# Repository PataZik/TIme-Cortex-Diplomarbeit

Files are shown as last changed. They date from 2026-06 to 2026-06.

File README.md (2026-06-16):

"# TIme-Cortex-Diplomarbeit" 

| Schüler/in | Individuelle Themenstellung | Abteilung | Verantwortlich |
|---|---|---|---|
| Patrik Alzo | Implementierung einer Datenbank zur Speicherung der Arbeitszeitdaten sowie Entwicklung eines passenden Gehäuses. | IF | |
| Wessel Reinier de Koo |  Entwurf und Umsetzung einer Platine für ein RFID-Zeiterfassungssystem mit geeigneten Mikrocontrollern und Komponenten. | IF | Ja |
| Dorde Dimitrijevic | Umsetzung einer Webanwendung zur Darstellung und Verwaltung der im RFID-System erfassten Arbeitszeiten. | IF | |
| Pascal Zierl | Entwicklung eines stabilen Programmcodes für die sichere Verarbeitung und Übertragung von RFID-Daten im Zeiterfassungssystem. | IF | |

De Koo Wessel Reinier
Auswahl und Testung verschiedener Mikrocontroller und weiterer Bauteile. Planung und Erstellung einer eigenen Platine sowie Zusammenbau aller Komponenten. Sicherstellung der Funktionsfähigkeit und Effizienz des Gesamtsystems.

Zierl Pascal
Entwicklung eines funktionierenden und kompatiblen Codes, der die erfassten Daten zuverlässig an die Webanwendung übermittelt und dabei die Sicherheit der Daten gewährleistet.

Dimitrijevic Dorde
Erstellung einer Webanwendung zum Zugriff auf die erfassten Daten. Eine zentrale Funktion ist die Einsicht der dokumentierten Arbeitszeiten über eine benutzerfreundliche Oberfläche.

Alzo Patrik
Planung, Test und Erstellung einer Datenbank zur Speicherung der erfassten Daten. Zusätzlich Konstruktion, Druck und Prüfung eines selbst entworfenen Gehäuses für die Hardware.

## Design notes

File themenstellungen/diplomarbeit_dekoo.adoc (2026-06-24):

== Themenstellung von Wessel de Koo

[.lead]
Eine funktionsfähige, getestete Platine mit RFID-Lesegerät, die Mitarbeiterchips fehlerfrei erkennt und die Daten an die nachfolgenden Systeme weitergibt.
Das Modul bildet die Grundlage für die gesamte Zeiterfassung.

Die vorliegende Arbeit ist Teil des Gesamtprojekts _TimeCortex_, eines RFID-gestützten Zeiterfassungssystems.
Während sich andere Teilarbeiten mit dem Gehäuse, der Datenbank und der Weboberfläche befassen, behandelt dieser Abschnitt die zentrale Hardwarekomponente: eine eigens entworfene Leiterplatte, auf der ein Mikrocontroller, ein RFID-Lesemodul, ein Display sowie eine akkugepufferte Stromversorgung zusammengeführt werden.
Das Untersuchungsanliegen umfasst die Auswahl und Testung verschiedener Mikrocontroller und weiterer Bauteile, die Planung und Erstellung einer eigenen Platine, den Zusammenbau aller Komponenten sowie die Sicherstellung der Funktionsfähigkeit und Effizienz des Gesamtsystems.

Die Arbeit folgt dabei bewusst dem realen Entwicklungsverlauf:
Zunächst werden die theoretischen Grundlagen der eingesetzten Technologien erläutert, anschließend wird die Bauteilauswahl begründet, danach das Platinendesign beschrieben und schließlich die Fertigung, Bestückung und schrittweise Inbetriebnahme des Prototyps dokumentiert.

=== Theoretische Grundlagen

Bevor konkrete Bauteile ausgewählt und zu einer Schaltung verbunden werden können, ist ein Verständnis der zugrunde liegenden Technologien erforderlich.
Dieses Kapitel beschreibt daher zunächst allgemein das Funktionsprinzip der RFID-Technologie, die Einordnung von Mikrocontrollern gegenüber Mikrocomputern und die grundlegenden Begriffe des Leiterplattenentwurfs.
Erst auf dieser Basis lassen sich die späteren Entwurfsentscheidungen nachvollziehbar begründen.

==== RFID-Technologie

_RFID_ steht für _Radio-Frequency Identification_ und bezeichnet ein Verfahren zur kontaktlosen Identifikation von Objekten über elektromagnetische Felder (vgl. <<wiki-rfid>>).
Ein RFID-System besteht grundsätzlich aus zwei Komponenten: einem _Lesegerät_ (Reader, in der Normsprache _PCD_ – Proximity Coupling Device) und einem _Transponder_ (Tag, in der Normsprache _PICC_ – Proximity Integrated Circuit Card).
Der Transponder trägt einen kleinen Mikrochip mit einer eindeutigen Kennung sowie eine Antenne in Form einer Spule.

Man unterscheidet grundsätzlich zwischen _aktiven_ und _passiven_ Transpondern.
Aktive Transponder besitzen eine eigene Energiequelle und können dadurch größere Reichweiten erzielen, sind aber teurer und wartungsbedürftig.
Passive Transponder – wie die in dieser Arbeit verwendeten Mitarbeiterchips – besitzen keine eigene Energieversorgung, sondern beziehen die zum Betrieb nötige Energie aus dem Feld des Lesegeräts.
Genau diese Eigenschaft macht sie für eine Zeiterfassung ideal:
Die Chips sind günstig, wartungsfrei und praktisch unbegrenzt haltbar.

Das physikalische Grundprinzip eines passiven HF-Systems ist die _induktive Kopplung_.
Das Lesegerät erzeugt über seine Antennenspule ein magnetisches Wechselfeld mit einer Trägerfrequenz von 13,56 MHz.
Befindet sich die Spule des Transponders in diesem Feld, so wird darin nach dem Induktionsgesetz eine Spannung induziert, die den Chip mit Energie versorgt – das System verhält sich also wie ein lose gekoppelter Transformator (vgl. <<iso-14443-guide>>).
Die Datenübertragung vom Transponder zurück zum Lesegerät erfolgt durch _Lastmodulation_:
Der Transponder verändert im Takt seiner Antwortdaten den Stromverbrauch seiner Spule, was als kleine Rückwirkung im Feld des Lesegeräts messbar ist.

Damit eine effiziente Energie- und Signalübertragung stattfindet, müssen Lese- und Transponderantenne auf die Trägerfrequenz abgestimmt sein.
Die Resonanzfrequenz eines solchen Schwingkreises aus Spuleninduktivität latexmath:[L] und Kapazität latexmath:[C] ergibt sich aus der bekannten Thomson-Gleichung:

[latexmath]
++++
f_{res} = \frac{1}{2\pi\sqrt{L\,C}}
++++

Für 13,56 MHz wird die Antenne also so dimensioniert, dass latexmath:[f_{res}] möglichst nahe an der Trägerfrequenz liegt.
Eine schlecht abgestimmte Antenne verringert die Reichweite drastisch – ein Aspekt, der beim späteren Platinenlayout zu beachten ist, da Kupferflächen und Bauteile in der Nähe der Antenne deren Abstimmung verstimmen können.

Auf der Protokollebene ist für diese Arbeit die Normenfamilie _ISO/IEC 14443_ maßgeblich, die den De-facto-Standard für kontaktlose Chipkarten im Nahbereich (bis etwa 10 cm) definiert (vgl. <<iso-14443-guide>>).
Die Norm gliedert sich in mehrere Teile, die jeweils einen Aspekt der Kommunikation festlegen.

.Aufbau der Normenfamilie ISO/IEC 14443
[cols="1,3",options="header"]
|===
| Teil | Inhalt
| Teil 1 | Physikalische Eigenschaften der Karte (Abmessungen, Umweltanforderungen).
| Teil 2 | Hochfrequenz-Leistungs- und Signalschnittstelle (Modulation, Feldstärke, Typ A und Typ B).
| Teil 3 | Initialisierung und Antikollision – die Auswahl genau einer Karte aus mehreren im Feld.
| Teil 4 | Übertragungsprotokoll für den Datenaustausch nach erfolgter Auswahl.
|===

Innerhalb dieser Norm ist die von NXP entwickelte _MIFARE_-Familie der mit Abstand verbreitetste Kartentyp und nutzt die Variante Typ A (vgl. <<mifare-an>>).
Für die Zeiterfassung ist dabei nicht der oft verschlüsselte Speicherinhalt einer MIFARE-Karte entscheidend, sondern bereits die im Antikollisionsverfahren übertragene eindeutige Seriennummer, die _UID_ (Unique Identifier).
Jeder Mitarbeiterchip besitzt eine solche, weltweit praktisch eindeutige UID, die sich ohne Authentifizierung auslesen lässt und damit als digitaler Schlüssel zur Identifikation der Person dient.
Genau diese UID liest das in dieser Arbeit aufgebaute Modul aus und reicht sie an die nachgelagerten Systeme weiter.

Der grundsätzliche Ablauf einer Erfassung lässt sich als Sequenz zwischen Lesegerät und Transponder darstellen.

[plantuml,format=svg]
----
@startuml
skinparam shadowing false
actor "Mitarbeiter" as user
participant "Lesegerät\n(PCD / PN532)" as reader
participant "Chip\n(PICC / MIFARE)" as card

user -> card : Chip an Leser halten
reader -> card : 13,56-MHz-Feld (Energie)
note right of card : Induzierte Spannung\nversorgt den Chip
reader -> card : REQA (Karte im Feld?)
card --> reader : ATQA (Antwort)
reader -> card : Antikollision / SELECT
card --> reader : UID
reader -> reader : UID an Mikrocontroller
@enduml
----

==== Mikrocontroller und Mikrocomputer

Das Herzstück jeder eingebetteten Schaltung ist die Recheneinheit, die Sensoren ausliest, Aktoren ansteuert und die Programmlogik ausführt.
Hier ist begrifflich zwischen einem _Mikrocomputer_ und einem _Mikrocontroller_ zu unterscheiden, da diese Wahl die gesamte Architektur der Platine prägt.

Ein _Mikrocomputer_ – ein typischer Vertreter ist der Raspberry Pi – ist im Kern ein vollwertiger, wenn auch kleiner Computer.
Er besitzt einen leistungsfähigen Prozessor, mehrere hundert Megabyte bis Gigabyte Arbeitsspeicher und führt in der Regel ein vollwertiges Betriebssystem wie Linux aus.
Dadurch eignet er sich für rechenintensive Aufgaben wie Bildverarbeitung oder das Betreiben von Servern, benötigt aber vergleichsweise viel Energie, eine geregelte Stromversorgung und einen Massenspeicher.

Ein _Mikrocontroller_ hingegen ist ein hochintegrierter Ein-Chip-Rechner, der Prozessorkern, Arbeitsspeicher (RAM), Programmspeicher (Flash) und zahlreiche Peripherieschnittstellen auf einem einzigen Baustein vereint.
Er besitzt kein Betriebssystem im klassischen Sinn, sondern führt ein einzelnes, fest eingebranntes Programm (die _Firmware_) aus.
Mikrocontroller sind dafür ausgelegt, mit minimalem Energieverbrauch direkt mit der physischen Welt zu interagieren – sie lesen digitale und analoge Eingänge, schalten Ausgänge und kommunizieren über serielle Busse mit Sensoren und Modulen.

Für ein Zeiterfassungsterminal, das im Wesentlichen einen RFID-Chip auslesen, eine Information anzeigen und das Ergebnis über das Netzwerk versenden soll, ist ein Mikrocontroller die naheliegende Wahl.
Die Aufgabe ist nicht rechenintensiv, dafür sind geringer Stromverbrauch (für den Akkubetrieb), geringe Kosten und eine direkte Anbindung von Peripherie über Busse wie _I²C_ entscheidend.
Ein vollwertiger Mikrocomputer wäre an dieser Stelle deutlich überdimensioniert, teurer und energiehungriger.

Die Kommunikation mit den Peripheriemodulen erfolgt im vorliegenden Projekt überwiegend über den _I²C-Bus_ (Inter-Integrated Circuit).
Dieser serielle Zweidraht-Bus benötigt lediglich zwei Leitungen – eine Taktleitung (_SCL_) und eine Datenleitung (_SDA_) – und erlaubt es, mehrere Bausteine mit jeweils eigener Adresse an denselben zwei Leitungen zu betreiben.
Diese Eigenschaft ist für ein platzsparendes Platinendesign besonders attraktiv, da sowohl das RFID-Modul als auch das Display über dieselben beiden Leitungen angebunden werden können.
Beide Leitungen sind als _Open-Drain_ ausgeführt und benötigen daher Pull-up-Widerstände, ein Detail, das im Schaltungsentwurf wieder aufgegriffen wird.

==== Grundlagen des Platinenentwurfs

Eine _Leiterplatte_ (engl. _Printed Circuit Board_, PCB) ist der mechanische und elektrische Träger einer elektronischen Schaltung.
Sie besteht aus einem isolierenden Grundmaterial – üblicherweise dem glasfaserverstärkten Epoxidharz _FR4_ – auf das eine oder mehrere Lagen Kupfer aufgebracht sind.
Aus diesen Kupferlagen werden durch ein fotochemisches Ätzverfahren die _Leiterbahnen_ herausgearbeitet, welche die Bauteile elektrisch miteinander verbinden und damit die früher übliche fliegende Verdrahtung ersetzen.

Der Entwurf einer Leiterplatte verläuft in zwei klar getrennten Schritten, die auch in dieser Arbeit die Gliederung vorgeben.

Im ersten Schritt entsteht der _Schaltplan_ (Schematic).
Er ist eine rein logische, abstrakte Darstellung der Schaltung:
Er beschreibt, _welche_ Bauteile es gibt und _wie_ sie elektrisch verbunden sind, ohne eine Aussage über ihre physische Anordnung zu treffen.
Bauteile werden durch genormte Symbole repräsentiert, Verbindungen durch Linien (_Netze_).

Im zweiten Schritt folgt das _Layout_ (PCB-Design).
Hier werden die im Schaltplan definierten Bauteile durch ihre realen _Footprints_ – die exakten Lötflächen und Bohrungen des physischen Gehäuses – ersetzt und physisch auf der Platinenfläche platziert.
Anschließend werden die logischen Netze des Schaltplans als reale Kupferbahnen verlegt (das sogenannte _Routing_).
Dabei sind zahlreiche physikalische Randbedingungen zu beachten, etwa Mindestabstände zwischen Leiterbahnen, ausreichende Bahnbreiten für höhere Ströme und eine durchgehende Massefläche zur Verbesserung der Störfestigkeit.

Man unterscheidet Leiterplatten nach der Anzahl ihrer Kupferlagen.
Einfache Schaltungen kommen mit einer einseitigen Platine aus, während komplexe Designs vier oder mehr Lagen benötigen.
Für das vorliegende Projekt wurde eine _zweilagige_ Platine gewählt, die einen guten Kompromiss zwischen Fertigungskosten und Verdrahtungsfreiheit darstellt:
Die Bauteile und der Großteil der Signale liegen auf der Oberseite, während die Unterseite überwiegend als durchgehende Massefläche und für kreuzende Verbindungen genutzt wird.
Verbindungen zwischen den beiden Lagen werden über metallisierte Bohrungen, sogenannte _Vias_, hergestellt.

Der gesamte Entwurf wurde in der webbasierten EDA-Software _EasyEDA_ erstellt, deren Projektdateien (Schaltplan und Layout) eine zentrale Quelle dieser Arbeit bilden.
EasyEDA ist eng mit dem Fertiger JLCPCB sowie dem Bauteilkatalog von LCSC verzahnt, wodurch ein durchgängiger Weg vom Schaltplan bis zur bestellten Platine entsteht.

=== Recherche der optimalen Komponenten

Ein wesentlicher Teil dieser Arbeit bestand in der sorgfältigen Auswahl der Bauteile.
Diese Recherche nahm – wie aus dem Begleitprotokoll ersichtlich – einen erheblichen Anteil der Projektzeit in Anspruch, da jede Komponente nicht nur ihre Funktion erfüllen, sondern auch hinsichtlich Betriebsspannung, Schnittstellen, Verfügbarkeit, Lieferzeit und Kosten zum Gesamtsystem passen muss.
Dieses Kapitel begründet die getroffene Auswahl, indem es jeweils zunächst die Anforderungen und alternative Lösungen darstellt und anschließend die konkrete Entscheidung herleitet.

==== Vergleich und Auswahl des Mikrocontrollers

Als zentrale Anforderung an den Mikrocontroller galt eine integrierte WLAN-Schnittstelle, da die erfassten Zeitstempel an ein nachgelagertes Backend übertragen werden müssen.
Weiterhin waren ein niedriger Energieverbrauch für den Akkubetrieb, eine ausreichende Anzahl an GPIO-Pins, ein I²C-Controller sowie geringe Kosten und gute Verfügbarkeit gefordert.

Für die Vorauswahl wurden drei in der Praxis verbreitete Plattformen gegenübergestellt.

.Vergleich möglicher Mikrocontroller-Plattformen
[cols="1,1,1,1",options="header"]
|===
| Kriterium | ATmega328P (Arduino Uno) | ESP8266 | ESP32-C3
| Funk | keiner | WLAN | WLAN + Bluetooth LE
| Kern | 8-bit AVR, 16 MHz | 32-bit, 80 MHz | 32-bit RISC-V, bis 160 MHz
| GPIO | ~20 | begrenzt (~9 nutzbar) | 15 (modulabhängig)
| Betriebsspannung | 5 V | 3,3 V | 3,3 V
| Eignung | kein Funk | wenig freie Pins | sehr gut geeignet
|===

Der _ATmega328P_, bekannt aus dem Arduino Uno, schied früh aus, da er über keinerlei Funkschnittstelle verfügt;
ein externes WLAN-Modul hätte die Schaltung unnötig verkompliziert und verteuert.
Der _ESP8266_ bringt zwar WLAN mit, stellt aber nur sehr wenige frei nutzbare GPIO-Pins bereit und besitzt einige Pins mit Boot-Sonderfunktionen, was den Schaltungsentwurf einschränkt.

Die Wahl fiel auf den _ESP32-C3_ von Espressif, konkret auf das Modul _ESP32-C3-WROOM-02-H4_.
Dieses Modul vereint einen 32-bit-RISC-V-Single-Core-Prozessor mit bis zu 160 MHz Taktfrequenz, 400 KB SRAM und 4 MB integriertem Flash-Speicher und integriert sowohl 2,4-GHz-WLAN (Wi-Fi 4) als auch Bluetooth 5 (LE) auf einem einzigen Baustein mit aufgedruckter PCB-Antenne (vgl. <<esp-c3-ds>>, <<esp-c3-soc>>).
Es bricht 15 GPIO-Pins heraus, verfügt über einen I²C-Controller und arbeitet mit 3,3 V Betriebsspannung – ein Wert, der zugleich die Spannungsebene des gesamten Designs vorgibt.

Ein für die Programmierung praktischer Vorteil des ESP32-C3 ist sein integrierter _USB-Serial/JTAG-Controller_ sowie die unkomplizierte Unterstützung durch das Arduino-Framework, das die Entwicklung der Firmware erheblich vereinfacht.
Im konkreten Anwendungsfall fungiert der ESP32-C3 als zentrale Steuereinheit:
Er liest über I²C die UID vom RFID-Modul, zeigt Rückmeldungen auf dem Display an und überträgt die Erfassungsdaten per WLAN an das Backend.
Damit deckt ein einziger, kostengünstiger Baustein sämtliche Steuerungs- und Kommunikationsaufgaben ab.

==== Vergleich und Auswahl des RFID-Moduls

Für das Auslesen der Mitarbeiterchips standen im Wesentlichen zwei am Markt verbreitete Modulfamilien zur Auswahl, die beide bei 13,56 MHz arbeiten.

Die erste Option ist der weit verbreitete und sehr günstige _MFRC522_.
Dieser Leser unterstützt jedoch ausschließlich die SPI-Schnittstelle zuverlässig und ist auf MIFARE-Karten nach ISO 14443A beschränkt.
Die zweite Option ist der _PN532_ von NXP, ein deutlich vielseitigerer Baustein.

Die Entscheidung fiel auf ein _PN532-Modul_, das gleich mehrere Vorteile bietet (vgl. <<pn532-um>>, <<elechouse-pn532>>).
Der PN532 ist ein hochintegrierter Transceiver für die kontaktlose Kommunikation bei 13,56 MHz, der nicht nur als Lesegerät für ISO-14443A/MIFARE-Karten dient, sondern auch FeliCa und den vollständigen NFC-Standard (inklusive Peer-to-Peer- und Kartenemulationsmodus) beherrscht.
Sein entscheidender praktischer Vorteil ist die Unterstützung dreier Host-Schnittstellen – SPI, High-Speed-UART (HSU) und _I²C_ – die sich am Modul per Schalter oder Lötbrücke umstellen lassen.

Für dieses Projekt wurde der PN532 im _I²C-Modus_ betrieben.
Damit kann er sich denselben Zweidraht-Bus mit dem Display teilen und benötigt nur zwei Signalleitungen zum Mikrocontroller, was das Layout vereinfacht und Pins am ESP32-C3 spart.
Der PN532 arbeitet mit einer Betriebsspannung von 2,7 V bis 5,5 V und besitzt mehrere Stromsparmodi (im Hard-Power-Down typisch nur 1 µA), was dem Ziel eines energieeffizienten, akkubetriebenen Geräts entgegenkommt (vgl. <<pn532-ds>>).
Da der PN532 bereits die komplette Hochfrequenz-Analogtechnik samt Modulator und Demodulator integriert, übernimmt er die anspruchsvolle Aufgabe der Felderzeugung und Signalauswertung vollständig und liefert dem ESP32-C3 fertig dekodierte UIDs.

==== Auswahl weiterer Bauteile (Display, Stromversorgung, Ladeelektronik)

Neben den beiden Hauptkomponenten waren zahlreiche weitere Bauteile auszuwählen, die das System erst eigenständig betriebsfähig machen.

*Display.*
Zur Rückmeldung an den Benutzer – etwa der Anzeige der gelesenen UID oder einer Bestätigung – wurde ein zeichenorientiertes _LCD vom Typ 1602_ (16 Zeichen × 2 Zeilen, vom Hersteller mit „QAPASS“ bedruckt) gewählt.
Solche Displays basieren auf dem Industriestandard-Controller _HD44780_.
In ihrer Grundform würden sie jedoch zahlreiche parallele Datenleitungen benötigen.
Daher wurde eine Variante mit aufgelötetem _I²C-Adapter_ auf Basis des Portexpanders _PCF8574_ verwendet, der die parallele Ansteuerung auf zwei I²C-Leitungen reduziert (vgl. <<lcd-i2c>>).
Dadurch fügt sich das Display nahtlos in den ohnehin vorhandenen I²C-Bus ein und teilt sich diesen mit dem PN532; die Anzeige besitzt typischerweise die I²C-Adresse 0x27.

*Stromversorgung.*
Da sowohl der ESP32-C3 (3,3 V) als auch der PN532 und das Display von einer stabilen Spannung versorgt werden müssen, wird ein _Low-Dropout-Spannungsregler_ (LDO) benötigt.
Die Wahl fiel auf den _AP2112K-3.3_ von Diodes Incorporated, einen CMOS-LDO im kompakten SOT-23-5-Gehäuse.
Er liefert eine fest eingestellte Ausgangsspannung von 3,3 V mit einer Genauigkeit von ±1,5 % bei einem maximalen Ausgangsstrom von 600 mA und einer typischen Dropout-Spannung von nur 400 mV bei Volllast (vgl. <<ap2112-ds>>).
Die geringe Dropout-Spannung ist im Akkubetrieb entscheidend, da die Zellspannung eines Lithium-Ionen-Akkus im Betrieb absinkt und ein Regler mit hohem Spannungsabfall die nutzbare Akkukapazität verschwenden würde.
Ein zusätzlicher Vorteil ist der _Enable_-Eingang, über den sich der Regler abschalten lässt.

*Ladeelektronik und Energiequelle.*
Als Energiequelle dient ein wiederaufladbarer Lithium-Ionen-Akku der Baugröße _18650_, für den auf der Platine ein Batteriehalter (BT1) vorgesehen ist.
Zum Laden dieses Akkus über die USB-C-Buchse wird der weit verbreitete Lade-IC _TP4056_ eingesetzt, ein linearer Einzelzellen-Lader, der das normgerechte Constant-Current/Constant-Voltage-Verfahren (CC/CV) mit einer Ladeschlussspannung von 4,2 V umsetzt (vgl. <<tp4056-ds>>).
Der maximale Ladestrom wird über einen einzigen Widerstand (latexmath:[R_{PROG}]) eingestellt, wobei näherungsweise gilt:

[latexmath]
++++
I_{BAT} = \frac{1200\,\text{V}\cdot\Omega}{R_{PROG}}
++++

Mit dem im Design verwendeten Widerstand von 1,2 kΩ ergibt sich somit ein Ladestrom von etwa 1 A.
Der TP4056 signalisiert über zwei LED-Ausgänge den laufenden Ladevorgang sowie das Ladeende.

*USB-C-Buchse.*
Die Energiezufuhr erfolgt über eine moderne _USB-C-Buchse_.
Damit ein Standard-USB-C-Netzteil die Buchse überhaupt als Verbraucher (Sink) erkennt und Strom freigibt, müssen die beiden Konfigurationskanäle (_CC1_ und _CC2_) jeweils über einen 5,1-kΩ-Widerstand auf Masse gezogen werden (vgl. <<usbc-cc>>).
Werden diese Pull-down-Widerstände vergessen, liefert ein USB-C-Netzteil keinen oder nur einen stark begrenzten Strom – ein klassischer und leicht zu übersehender Designfehler, der hier von vornherein berücksichtigt wurde.

Ergänzt wird die Schaltung durch zwei Taster für _Reset_ und _Boot_ (zur Programmierung des ESP32-C3), einen Schiebeschalter zum Ein- und Ausschalten des Geräts sowie die für den I²C-Bus erforderlichen Pull-up-Widerstände und Stützkondensatoren.

=== Planung und Design der Platine

Mit den ausgewählten Bauteilen konnte der eigentliche Entwurf beginnen.
Dieser gliedert sich, wie in den Grundlagen beschrieben, in die Erstellung des Schaltplans und das anschließende PCB-Layout.

==== Erstellung des Schaltplans

Der Schaltplan führt alle ausgewählten Komponenten zu einem logisch verbundenen Gesamtsystem zusammen.
Im Zentrum steht der ESP32-C3 (U1), um den herum sich die Funktionsblöcke Stromversorgung, RFID-Leser und Display gruppieren.

.Vollständiger Schaltplan des TimeCortex-Moduls in EasyEDA
[#fig-schaltplan]
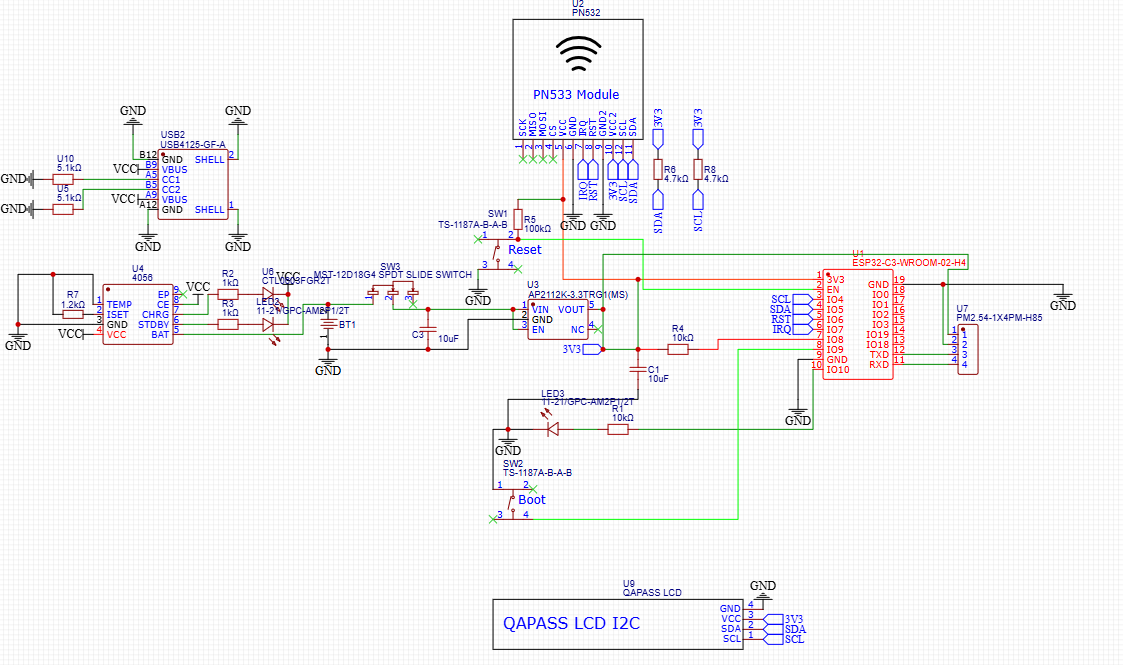
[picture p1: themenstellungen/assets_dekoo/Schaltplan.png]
Schaltplan mit ESP32-C3


Die Architektur der Schaltung lässt sich in drei logische Domänen einteilen, deren Zusammenspiel das folgende Blockdiagramm verdeutlicht.

[plantuml,format=svg]
----
@startuml
skinparam shadowing false
skinparam componentStyle rectangle

[USB-C-Buchse] as usb
[TP4056\nLade-IC] as charger
[18650-Akku] as bat
[Schiebeschalter] as sw
[AP2112K-3.3\nLDO 3,3 V] as ldo
[ESP32-C3\nWROOM-02] as mcu
[PN532\nRFID-Leser] as pn532
[LCD 1602\n(I2C)] as lcd

usb --> charger : 5 V (VBUS)
charger --> bat : Laden (CC/CV)
bat --> sw : Akkuspannung
sw --> ldo : geschaltet
ldo --> mcu : 3,3 V
ldo --> pn532 : 3,3 V
ldo --> lcd : 3,3 V
mcu <--> pn532 : I2C (SDA/SCL)
mcu <--> lcd : I2C (SDA/SCL)
mcu ..> [WLAN-Backend] : WLAN
@enduml
----

*Stromversorgungspfad.*
Die über die USB-C-Buchse (USB2) bereitgestellten 5 V (VBUS) gelangen zunächst an den Eingang des TP4056 (U4), der den 18650-Akku (BT1) lädt.
Die beiden CC-Leitungen der USB-C-Buchse sind über je einen 5,1-kΩ-Widerstand (U5, U10) mit Masse verbunden, sodass ein USB-C-Netzteil korrekt erkannt wird.
Der Ladestrom wird durch den PROG-Widerstand (R7, 1,2 kΩ) auf rund 1 A festgelegt;
zwei LEDs zeigen Lade- und Bereitschaftszustand an.
Die Akkuspannung wird über den Schiebeschalter (SW3) geführt und gelangt von dort an den Eingang des LDO (U3, AP2112K-3.3), der daraus die stabile 3,3-V-Versorgung für die gesamte restliche Schaltung erzeugt.
Eingangs- und Ausgangsseite des Reglers sind mit jeweils 10-µF-Kondensatoren (C1, C3) gestützt, wie es das Datenblatt für einen stabilen Betrieb fordert.

*Signal- und Busführung.*
Der RFID-Leser (U2, PN532) und das Display (U9) sind gemeinsam an den I²C-Bus des ESP32-C3 angeschlossen.
Da I²C-Leitungen als Open-Drain ausgeführt sind, befinden sich auf den Leitungen SDA und SCL die erforderlichen Pull-up-Widerstände (R6 und R8, je 4,7 kΩ), die den Bus in den definierten High-Pegel ziehen.
Der Reset-Taster (SW1) wirkt über einen Pull-up-Widerstand (R5, 100 kΩ) auf den EN-Pin des Mikrocontrollers, der Boot-Taster (SW2) auf den entsprechenden Strapping-Pin (IO9), sodass sich der ESP32-C3 für die Programmierung in den Download-Modus versetzen lässt.
Über den vierpoligen Stiftleisten-Header (U7) sind die UART-Signale (TXD/RXD) zum Aufspielen der Firmware nach außen geführt.

==== PCB-Layout und Fertigungsvorbereitung

Nach Fertigstellung des Schaltplans wurden die Bauteile auf der zweilagigen Platine platziert und die logischen Netze als Kupferbahnen verlegt.
Bei der Platzierung waren neben der reinen elektrischen Verbindung mehrere praktische Aspekte zu berücksichtigen.

.Layout (Routing) der zweilagigen Platine
[#fig-pcb]
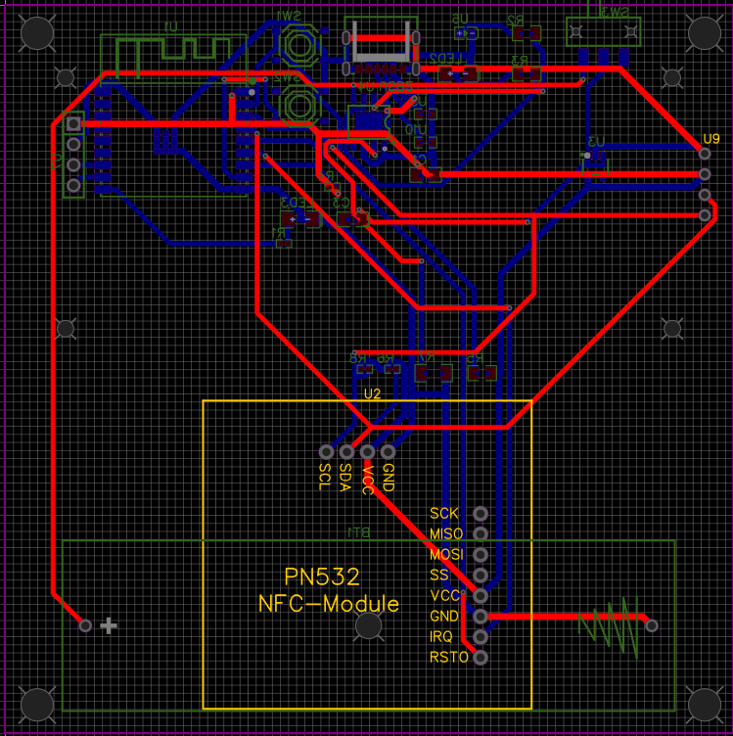
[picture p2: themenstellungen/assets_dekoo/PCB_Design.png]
Leiterbahn-Routing der zweilagigen Platine mit PN532-Bereich


Eine zentrale Designentscheidung betrifft die Anordnung des RFID-Lesers.
Die Antenne des PN532 darf nicht von Kupferflächen überdeckt werden, da diese als Wirbelstrombremse das 13,56-MHz-Feld dämpfen und so die Lesereichweite drastisch verringern würden.
Aus diesem Grund wurde dem PN532 ein eigener, klar abgegrenzter Bereich der Platine zugewiesen (im Layout deutlich als rechteckiger Block erkennbar).
Die übrigen Bauteile – Mikrocontroller, USB-Buchse, Ladeelektronik und der Batteriehalter – wurden auf der gegenüberliegenden Seite der Platine konzentriert.

Da das Ergebnis eines reinen 2D-Layouts schwer zu beurteilen ist, bietet EasyEDA eine fotorealistische 3D-Vorschau, mit der sich Bauteilplatzierung, Beschriftungen und mögliche Kollisionen vor der Fertigung überprüfen lassen.

.3D-Vorschau der Bestückungsseite (ESP32-C3, USB-C, Taster, Batteriehalter)
[#fig-3d-back]
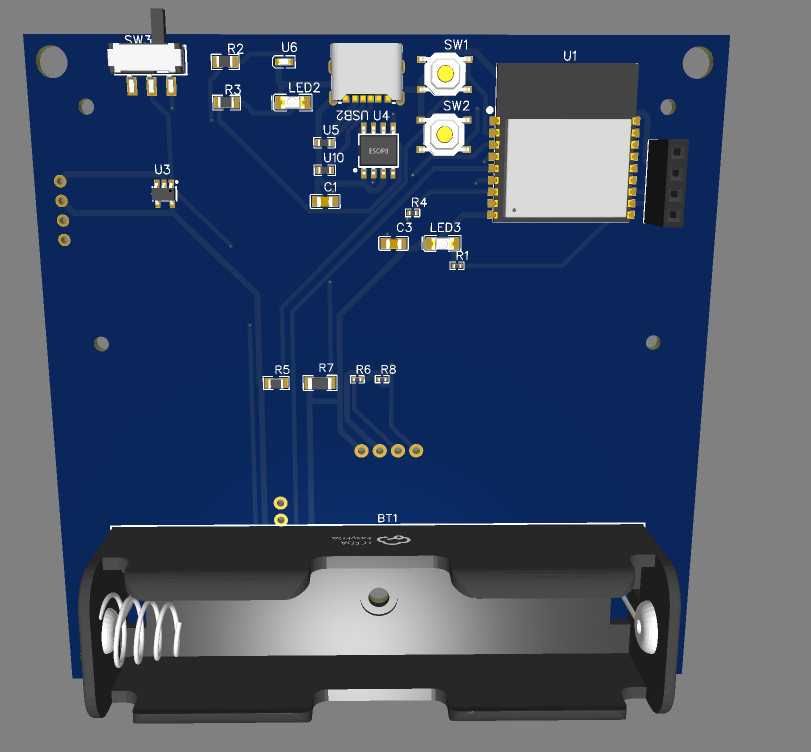
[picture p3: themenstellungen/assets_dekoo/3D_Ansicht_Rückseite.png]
3D-Ansicht der Komponentenseite


.3D-Vorschau der Leserseite mit Aufnahme für das PN532-Modul
[#fig-3d-front]
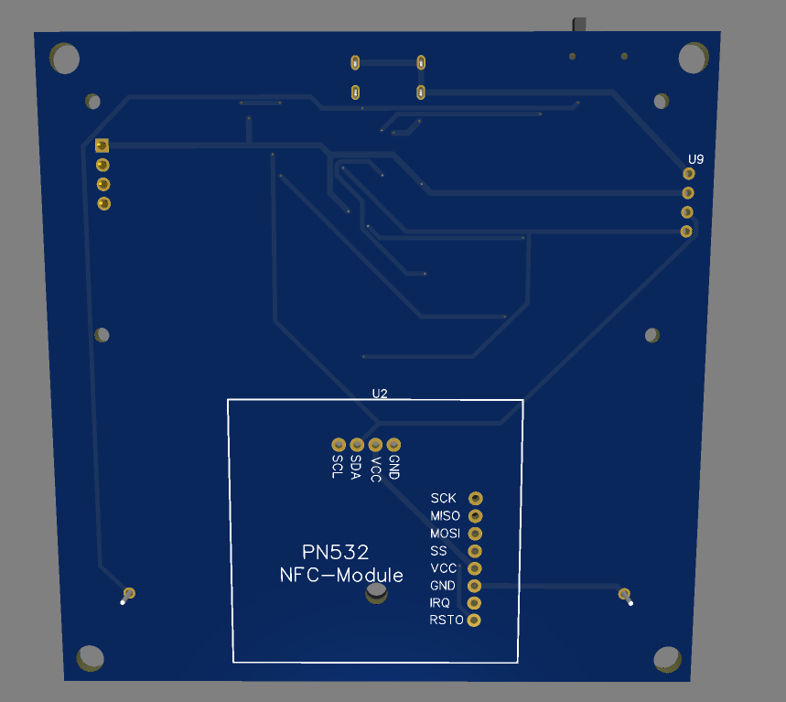
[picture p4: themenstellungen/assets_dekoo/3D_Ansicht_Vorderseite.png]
3D-Ansicht der RFID-Leserseite


In der 3D-Vorschau ist die durchdachte Aufteilung gut zu erkennen:
Auf der einen Seite befindet sich der dicht bestückte Bereich mit dem ESP32-C3-Modul, der USB-C-Buchse, den Reset- und Boot-Tastern, dem Schiebeschalter und dem Halter für den 18650-Akku.
Die gegenüberliegende Seite trägt die Anschlussfelder für das PN532-Modul sowie für das Display und hält die kritische Antennenregion frei von störendem Kupfer.

Nach der visuellen Kontrolle und einem automatischen Design-Rule-Check (DRC), der Mindestabstände und Bahnbreiten prüft, wurden die Fertigungsdaten erzeugt.
EasyEDA exportiert hierfür die branchenüblichen _Gerber-Dateien_, welche jede Kupfer-, Lötstopp- und Bestückungsdrucklage einzeln beschreiben, sowie eine Bohrdatei.
Diese Daten bilden die Grundlage für die Bestellung der Leiterplatte beim Fertiger.

=== Erstellung der Platine

Mit den fertigen Produktionsdaten konnte die Platine gefertigt und anschließend schrittweise zum Leben erweckt werden.

==== Fertigung der Leiterplatte

Die Fertigung der eigentlichen Leiterplatte erfolgte über einen industriellen Leiterplattenhersteller, an den die exportierten Gerber-Daten übermittelt wurden.
Der Hersteller belichtet, ätzt, bohrt und metallisiert die Lagen und versieht die Platine mit Lötstopplack (der das charakteristische farbige Erscheinungsbild erzeugt) sowie einem weißen Bestückungsdruck mit den Bauteilbezeichnungen.
Diese industrielle Fertigung erreicht eine Präzision und Reproduzierbarkeit, die mit einer manuell geätzten Platine im Schulkontext nicht erreichbar wäre, und ermöglicht zugleich die für die feinen Bauteile nötigen durchkontaktierten Vias.

Das Ergebnis ist eine professionell gefertigte Leiterplatte mit weißem Lötstopplack, die in der nächsten Phase bestückt wurde.

==== Grundbestückung und Inbetriebnahme

Ein Teil der Bauteile – insbesondere die feinen SMD-Komponenten der Stromversorgung – wurde im Rahmen der Grundbestückung auf die gelieferte Platine aufgebracht.
Das Ergebnis dieser Grundbestückung zeigt die folgende Abbildung der realen Baugruppe.

.Reale, grundbestückte Platine (Komponentenseite)
[#fig-real-front]
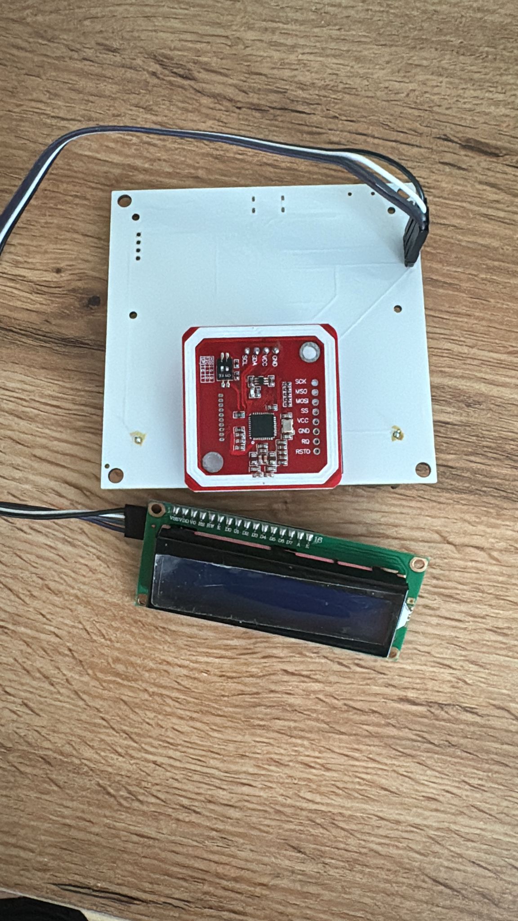
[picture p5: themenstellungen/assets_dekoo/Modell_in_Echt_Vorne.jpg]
Bestückte Platine mit ESP32-C3 und Batteriehalter


Auf der bestückten Platine sind das ESP32-C3-Modul, die USB-C-Buchse, die Taster, der Schiebeschalter sowie der Halter für den 18650-Akku deutlich zu erkennen.
Die weiße Platinenfarbe und der saubere Bestückungsdruck bestätigen die professionelle Fertigungsqualität.
In dieser Phase wurde die grundlegende Stromversorgung erstmals in Betrieb genommen und überprüft, bevor die empfindlicheren Module ergänzt wurden.

=== Lötung der fehlenden Komponenten

Nach der Grundbestückung mussten die beiden größeren Funktionsmodule – der RFID-Leser und das Display – manuell angelötet werden.
Diese Lötarbeiten wurden eigenständig durchgeführt und stellten einen wesentlichen praktischen Anteil der Arbeit dar.

==== RFID-Chip (PN532)

Das PN532-Modul wurde über seine Anschlussfelder mit der Platine verbunden.
Wie im Schaltplan vorgesehen, wurde der Leser im I²C-Modus betrieben, sodass lediglich die vier Leitungen für Versorgung (3,3 V, GND) und Bus (SDA, SCL) anzuschließen waren.
Beim manuellen Anlöten war besonders auf saubere, kurzschlussfreie Lötstellen zu achten, da bereits eine einzige Brücke zwischen SDA und SCL den gesamten Bus blockiert hätte.

==== Display

Anschließend wurde das LCD-1602-Display mit seinem I²C-Adapter angelötet.
Da das Display über denselben I²C-Bus wie der PN532 betrieben wird, teilen sich beide Module die Leitungen SDA und SCL und sind allein über ihre unterschiedlichen Busadressen unterscheidbar.
Die folgende Abbildung zeigt die Baugruppe mit dem angeschlossenen PN532-Modul (rote Platine) und dem LCD-Display.

.Manuell ergänztes PN532-Modul (rot) und LCD-Display
[#fig-real-back]
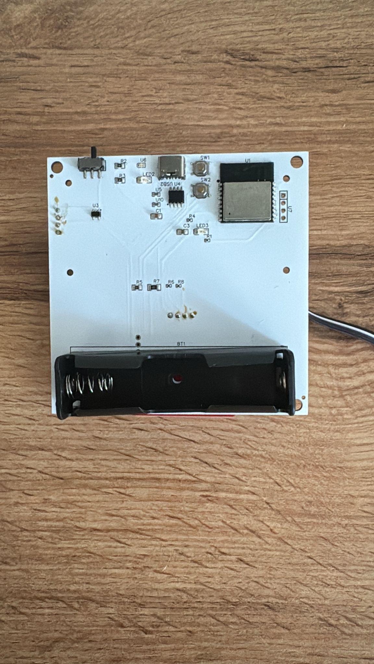
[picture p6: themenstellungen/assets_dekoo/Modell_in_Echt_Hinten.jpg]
Platine mit angelötetem PN532-Modul und LCD-Display


Mit dem Anlöten dieser beiden Module war die Hardware vollständig aufgebaut und bereit für die schrittweise Funktionsprüfung der einzelnen Komponenten.

=== Testen der einzelnen Komponenten

Eine bewährte Vorgehensweise bei der Inbetriebnahme komplexer Schaltungen ist das schrittweise Testen einzelner Funktionsblöcke, bevor das Gesamtsystem erprobt wird.
Dadurch lassen sich Fehler eingrenzen, da bei jedem Schritt nur eine überschaubare Zahl möglicher Fehlerquellen hinzukommt.

==== Test des Mikrocontrollers (ESP32-C3)

Zuerst wurde der Mikrocontroller selbst geprüft.
Über den UART-Header wurde eine einfache Firmware aufgespielt, die zunächst nur Statusmeldungen über die serielle Schnittstelle ausgibt.
Bereits dieser erste Test bestätigt mehrere Dinge gleichzeitig:
dass der LDO eine saubere 3,3-V-Versorgung liefert, dass das ESP32-C3-Modul korrekt verlötet ist und dass sich die Firmware über Boot- und Reset-Taster aufspielen lässt.
Erst nach erfolgreichem Bestehen dieses Grundtests wurde mit dem Anschluss der Peripherie fortgefahren.

==== Test des RFID-Lesers

Der zentrale Funktionstest galt dem RFID-Leser.
Hierfür wurde eine kompakte Testfirmware verwendet, die den PN532 über I²C initialisiert, dessen Firmware-Version ausliest und anschließend kontinuierlich nach Karten im Feld sucht.
Der nachfolgende Quelltext zeigt die wesentlichen Teile dieses Tests.

.Testfirmware zum Auslesen der UID über den PN532 (I²C)
[source,cpp]
----
#include <Wire.h>
#include <Adafruit_PN532.h>

#define SDA_PIN 5                        // <1>
#define SCL_PIN 4

Adafruit_PN532 nfc(-1, -1);              // <2>

void setup() {
  Serial.begin(115200);
  Wire.begin(SDA_PIN, SCL_PIN);          // <3>
  Wire.setClock(100000);

  nfc.begin();
  uint32_t v = nfc.getFirmwareVersion(); // <4>
  if (!v) {
    Serial.println("FAIL: PN532 nicht gefunden");
    while (1) delay(1000);               // <5>
  }
  Serial.print("OK: PN532 FW = 0x");
  Serial.println(v, HEX);

  nfc.SAMConfig();                        // <6>
}

void loop() {
  uint8_t uid[7];
  uint8_t uidLength;

  // Blocking read for an ISO14443A card in the field
  bool ok = nfc.readPassiveTargetID(PN532_MIFARE_ISO14443A,
                                     uid, &uidLength); // <7>
  if (ok) {
    Serial.print("UID: ");
    for (uint8_t i = 0; i < uidLength; i++) {          // <8>
      if (uid[i] < 0x10) Serial.print("0");
      Serial.print(uid[i], HEX);
      if (i < uidLength - 1) Serial.print(" ");
    }
    Serial.println();
    delay(800);
  }
}
----

<1> Festlegung der I²C-Pins; SDA an GPIO 5, SCL an GPIO 4 des ESP32-C3.
<2> Instanziierung des PN532 im I²C-Modus (beide SPI-Pins auf -1 gesetzt).
<3> Initialisierung des I²C-Busses mit 100 kHz Taktrate.
<4> Auslesen der Firmware-Version – dient zugleich als Erreichbarkeitstest des Bausteins.
<5> Wird der Leser nicht gefunden, hält das Programm bewusst an (klare Fehlerdiagnose).
<6> Konfiguration des _Security Access Module_; versetzt den PN532 in den Lesebetrieb.
<7> Blockierende Suche nach einer ISO-14443A-Karte; liefert bei Erfolg UID und deren Länge.
<8> Formatierte Ausgabe der UID als Hexadezimalwerte über die serielle Schnittstelle.

Dieser Test ist bewusst minimal gehalten und verzichtet auf Display und Netzwerk, um ausschließlich die Funktion des RFID-Lesers und der I²C-Kommunikation zu verifizieren.
Die zentrale Funktion ist `readPassiveTargetID`, die das gesamte in den Grundlagen beschriebene Antikollisions- und Auswahlverfahren kapselt und im Erfolgsfall die UID der Karte zurückliefert.
Wird beim Programmstart die Meldung mit gültiger Firmware-Version ausgegeben und beim Auflegen eines Chips dessen UID angezeigt, ist die Kernfunktion des Moduls nachgewiesen.

Im nächsten Schritt wurde die Ausgabe zusätzlich auf das LCD-Display geleitet, um die Funktion ohne angeschlossenen Computer überprüfen zu können.
Das folgende Beispiel skizziert exemplarisch, wie die ausgelesene UID auf dem I²C-Display dargestellt wird.

.Exemplarische Erweiterung zur UID-Anzeige auf dem LCD
[source,cpp]
----
#include <LiquidCrystal_I2C.h>

LiquidCrystal_I2C lcd(0x27, 16, 2);     // <1>

void showUid(uint8_t *uid, uint8_t len) {
  lcd.clear();
  lcd.setCursor(0, 0);
  lcd.print("UID:");                    // <2>
  lcd.setCursor(0, 1);
  for (uint8_t i = 0; i < len; i++) {   // <3>
    if (uid[i] < 0x10) lcd.print("0");
    lcd.print(uid[i], HEX);
    if (i < len - 1) lcd.print(" ");
  }
}
----

<1> Initialisierung des LCD über die I²C-Adresse 0x27 mit 16 Spalten und 2 Zeilen.
<2> Ausgabe einer Beschriftung in der ersten Zeile.
<3> Formatierte Ausgabe der UID-Bytes in der zweiten Zeile des Displays.

Das Ergebnis dieses kombinierten Tests ist in der folgenden Abbildung dokumentiert:
Das Display zeigt nach dem Auflegen eines Mitarbeiterchips dessen UID („23 D7 6A 1B“) an.

.Erfolgreicher Funktionstest – das Display zeigt die ausgelesene UID
[#fig-ersttest]
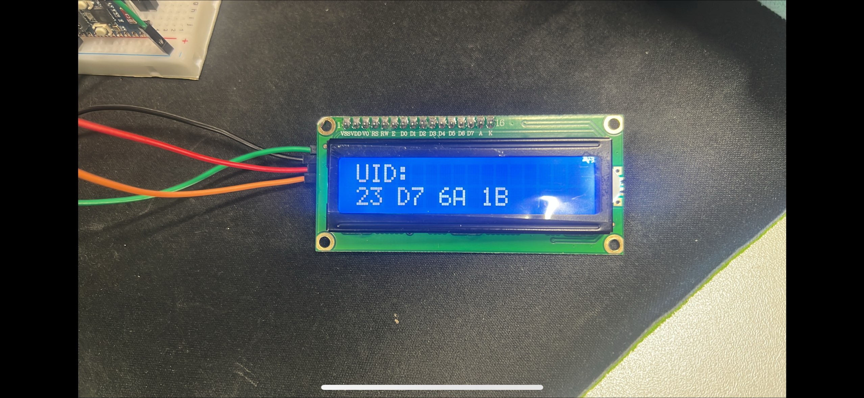
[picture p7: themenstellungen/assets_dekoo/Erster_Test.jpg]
LCD-Anzeige mit ausgelesener UID 23 D7 6A 1B


==== Test der Stromversorgung und Ladeelektronik

Parallel zu den Funktionstests wurde die Stromversorgung eingehend vermessen.
Geprüft wurden insbesondere die Ausgangsspannung des LDO unter Last, das korrekte Erkennen der USB-C-Buchse durch ein Netzteil sowie der Ladevorgang des Akkus über den TP4056.
Mit einem Multimeter wurden die Spannungswerte an den relevanten Knoten kontrolliert und das Verhalten der Lade- und Bereitschafts-LEDs überprüft.
Diese Messungen – im Begleitprotokoll als wiederholtes Messen von Spannungswerten und Signalverläufen dokumentiert – stellten sicher, dass die Versorgung unter allen Betriebszuständen (USB-Betrieb, Akkubetrieb, Ladebetrieb) stabil bleibt.

=== Testen des Prototypen

Nachdem die Einzelkomponenten ihre Funktion bewiesen hatten, wurde das Gesamtsystem als Prototyp erprobt.

==== Gesamtsystemtest und Fehleranalyse

Im Gesamtsystemtest wurde das Zusammenspiel aller Komponenten unter realistischen Bedingungen untersucht.
Dabei zeigte sich, dass der gemeinsame Betrieb von RFID-Leser und Display auf demselben I²C-Bus erwartungsgemäß funktioniert, solange beide Module unterschiedliche Busadressen verwenden.
Der typische Ablauf einer Erfassung im Gesamtsystem lässt sich als Programmfluss darstellen.

[plantuml,format=svg]
----
@startuml
skinparam shadowing false
start
:System einschalten (Schiebeschalter);
:3,3-V-Versorgung durch LDO;
:I2C-Bus initialisieren;
:PN532 initialisieren (SAMConfig);
if (PN532 erreichbar?) then (nein)
  :Fehlermeldung anzeigen;
  stop
else (ja)
endif
repeat
  :Auf Karte im Feld warten;
  if (Karte erkannt?) then (ja)
    :UID auslesen;
    :UID auf LCD anzeigen;
    :UID an Backend senden (WLAN);
  else (nein)
  endif
repeat while (Dauerbetrieb) is (ja)
stop
@enduml
----

Im Zuge der Erprobung traten – wie bei Hardwareprojekten üblich – verschiedene Probleme zutage, die einer systematischen Fehleranalyse unterzogen wurden.
Dazu gehörten die Analyse von Signalverläufen und Spannungswerten sowie das Aufspüren fehlerhafter Lötstellen.
Ein wiederkehrendes Thema war zudem die Verfügbarkeit der Bauteile:
Es wurden gezielt alternative Komponenten hinsichtlich Lieferzeit, Grenzwerten und Kosten recherchiert und auf Kompatibilität geprüft, um das Design lieferfähig und robust zu halten.

==== Optimierungen und Korrekturen

Aufbauend auf der Fehleranalyse wurden mehrere Iterationen von Korrekturen und Optimierungen durchgeführt.
Fehlerhafte Bauteile wurden ausgetauscht, Lötstellen nachgearbeitet und einzelne Komponenten gegen besser geeignete oder besser verfügbare Varianten ersetzt.
Abschließende Tests bestätigten die Stabilität der Schaltung über längere Betriebszeiträume hinweg.

Im Ergebnis liegt damit eine funktionsfähige, getestete Platine vor, die Mitarbeiterchips zuverlässig erkennt, deren UID ausliest, dem Benutzer eine Rückmeldung auf dem Display gibt und die ausgelesenen Daten für die Weitergabe an die nachgelagerten Systeme bereitstellt.
Das Modul erfüllt damit seine Rolle als Grundlage der gesamten Zeiterfassung.
Mögliche Weiterentwicklungen betreffen vor allem eine konsequentere Nutzung der Stromsparmodi des PN532 sowie des Deep-Sleep-Modus des ESP32-C3, um die Akkulaufzeit im Dauerbetrieb weiter zu erhöhen.

<<<
[bibliography]
=== Literaturverzeichnis

* [[[wiki-rfid,1]]] Wikipedia. "Radio-frequency identification". URL: https://en.wikipedia.org/wiki/Radio-frequency_identification (abgerufen am 24.6.2026).
* [[[iso-14443-guide,2]]] RFID Card. "ISO/IEC 14443 – Identification, Contactless, Proximity RFID Cards Standard". URL: https://www.rfidcard.com/iso-iec-14443-identification-contactless-proximity-rfid-cards-standard/ (abgerufen am 24.6.2026).
* [[[mifare-an,3]]] NXP Semiconductors. "MIFARE 14443A – Application Note". URL: https://www.nxp.com/docs/en/user-guide/141520.pdf (abgerufen am 24.6.2026).
* [[[esp-c3-ds,4]]] Espressif Systems. "ESP32-C3-WROOM-02 & ESP32-C3-WROOM-02U Datasheet". URL: https://www.espressif.com/sites/default/files/documentation/esp32-c3-wroom-02_datasheet_en.pdf (abgerufen am 24.6.2026).
* [[[esp-c3-soc,5]]] Espressif Systems. "ESP32-C3 Wi-Fi & Bluetooth 5 (LE) MCU". URL: https://www.espressif.com/en/products/socs/esp32-c3 (abgerufen am 24.6.2026).
* [[[pn532-um,6]]] NXP Semiconductors. "PN532 User Manual (UM0701-02)". URL: https://www.nxp.com/docs/en/user-guide/141520.pdf (abgerufen am 24.6.2026).
* [[[pn532-ds,7]]] NXP Semiconductors. "PN532/C1 – Near Field Communication (NFC) controller – Data Sheet". URL: https://www.nxp.com/docs/en/nxp/data-sheets/PN532_C1.pdf (abgerufen am 24.6.2026).
* [[[elechouse-pn532,8]]] Elechouse. "PN532 NFC RFID Module V4 – I2C, SPI, UART". URL: https://www.elechouse.com/product/pn532-nfc-rfid-module-v4/ (abgerufen am 24.6.2026).
* [[[ap2112-ds,9]]] Diodes Incorporated. "AP2112 – 600mA CMOS LDO Regulator with Enable – Data Sheet". URL: https://www.diodes.com/assets/Datasheets/AP2112.pdf (abgerufen am 24.6.2026).
* [[[tp4056-ds,10]]] Components101. "TP4056A Li-ion Battery Charging/Discharging Module – Pinout, Uses & Datasheet". URL: https://components101.com/modules/tp4056a-li-ion-battery-chargingdischarging-module (abgerufen am 24.6.2026).
* [[[usbc-cc,11]]] Hackaday. "All About USB-C: Resistors And Emarkers". URL: https://hackaday.com/2023/01/04/all-about-usb-c-resistors-and-emarkers/ (abgerufen am 24.6.2026).
* [[[lcd-i2c,12]]] Handson Technology. "I2C Serial Interface 1602 LCD Module – User Guide". URL: https://www.handsontec.com/dataspecs/module/I2C_1602_LCD.pdf (abgerufen am 24.6.2026).

<<<
=== Abbildungsverzeichnis

* <<fig-schaltplan>>
* <<fig-pcb>>
* <<fig-3d-back>>
* <<fig-3d-front>>
* <<fig-real-front>>
* <<fig-real-back>>
* <<fig-ersttest>>

<<<
=== Begleitprotokoll

[cols="1,5,1",options="header"]
|===
| Datum | Tätigkeit | Dauer

| 23.09.2025 | Lastenheft | 1 h
| 24.09.2025 | Lastenheft | 2 h
| 25.09.2025 | Theorie durchbesprochen | 3 h
| 30.09.2025 | Platine angefangen | 3 h
| 03.10.2025 | Platine weitergemacht | 3 h
| 04.10.2025 | Mit der Logistik auseinandergesetzt | 2 h
| 08.10.2025 | Platine erweitert | 3 h
| 10.10.2025 | Rodas Besprechung | 1 h
| 12.10.2025 | Platine erweitert | 2 h
| 17.10.2025 | Rodas Besprechung | 1 h
| 20.10.2025 | Platine erweitert | 2 h
| 24.10.2025 | Rodas Besprechung | 1 h
| 26.10.2025 | Platine erweitert | 1.5 h
| 27.10.2025 | Platine erweitert | 1.5 h
| 31.10.2025 | Platine überarbeitet | 5 h
| 05.11.2025 | Optionale Funktionen hinzugefügt | 2 h
| 07.11.2025 | Rodas Besprechung | 1 h
| 12.11.2025 | Platine verfeinert | 1 h
| 14.11.2025 | Display hinzugefügt | 3 h
| 15.11.2025 | Mit dem LCD-Display beschäftigt | 3 h
| 22.11.2025 | LCD-Display eingebaut | 3 h
| 02.01.2026 | LCD-Display verfeinert | 2 h
| 09.01.2026 | Rodas Besprechung | 3 h
| 24.01.2026 | Platine verfeinert und analysiert | 4 h
| 25.01.2026 | Komponenten ausgetauscht | 3 h
| 26.01.2026 | Rodas Besprechung | 4 h
| 13.02.2026 | Analyse alternativer Bauteile hinsichtlich Lieferzeit | 5 h
| 16.02.2026 | Ersatz- bzw. Alternativkomponenten recherchiert und Kompatibilität verifiziert | 5 h
| 19.02.2026 | Abgleich von Datenblättern hinsichtlich Grenzwerte und Betriebsspannungen | 4 h
| 20.02.2026 | Kostenvergleich verschiedener Bauteiloptionen durchgeführt | 5 h
| 01.03.2026 | Beginn der Lötarbeiten an der Platine | 3 h
| 04.03.2026 | Ersten Funktionstest der Baugruppe durchgeführt | 4 h
| 05.03.2026 | Abstimmung und Planung der nächsten Entwicklungsschritte | 4 h
| 07.03.2026 | Einzeltests der verbauten Komponenten durchgeführt | 6 h
| 08.03.2026 | Fehlersuche und Optimierung nach Ersttests durchgeführt | 3 h
| 10.03.2026 | Erweiterung der Lötarbeiten und Nachbearbeitung fehlerhafter Verbindungen | 5 h
| 11.03.2026 | Optimierung der Baugruppe weitergeführt | 2 h
| 11.03.2026 | Fortsetzung der Lötarbeiten und Vervollständigung der Bestückung der Platine | 4 h
| 12.03.2026 | Fehlersuche und Analyse von Signalverläufen sowie Spannungswerten | 5 h
| 13.03.2026 | Austausch fehlerhafter Bauteile und Nacharbeit an Lötstellen | 3 h
| 14.03.2026 | Weitere Tests und Fehleranalyse durchgeführt | 3 h
| 14.03.2026 | Abschließende Tests und Optimierung der Schaltung hinsichtlich Stabilität | 6 h
| 15.03.2026 | Anpassungen basierend auf Testergebnissen | 3 h
| 16.04.2026 | Nachbearbeitung und kleinere Optimierungen an der Schaltung durchgeführt | 3 h
| 24.04.2026 | Rodas Besprechung | 2 h
| 05.05.2026 | Weitere Arbeiten zur Fertigstellung der Platine durchgeführt | 3 h
| 06.05.2026 | Begonnen mit dem Schreiben der Diplomarbeit | 3 h
| 22.05.2026 | Spannungswerte und Signalverläufe erneut gemessen | 3 h
| 25.05.2026 | Finalen Testlauf der Platine durchgeführt | 4 h
| 29.05.2026 | Letzte Fehler behoben und Platine fertiggestellt | 3 h

2+| *Summe* | *152 h*
|===

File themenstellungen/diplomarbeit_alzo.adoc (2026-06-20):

== Themenstellung von Patrik Alzo

[.lead]
Planung, Test und Erstellung einer Datenbank zur Speicherung der erfassten Daten.
Zusätzlich Konstruktion, Druck und Prüfung eines selbst entworfenen Gehäuses für die Hardware.

Die vorliegende Arbeit ist Teil des Gesamtprojekts _TimeCortex_, eines RFID-gestützten Zeiterfassungssystems.
Während die anderen Teilarbeiten die Platine, den Mikrocontroller-Code und die Webanwendung behandeln, befasst sich dieser Abschnitt mit zwei voneinander getrennten, aber für das Gesamtsystem zentralen Bausteinen: dem _physischen Gehäuse_, das die Hardware schützt und benutzbar macht, sowie der _Datenbank_, in der sämtliche erfassten Arbeitszeitdaten dauerhaft und konsistent gespeichert werden.
Ergänzend wird der serverseitige Zugriff auf diese Datenbank mit PHP sowie die clientseitige Aufbereitung der Daten mit JavaScript beschrieben, da erst das Zusammenspiel dieser Schichten aus den gespeicherten Rohdaten eine nutzbare Anwendung macht.

=== Grundlagen des 3D-Druckes

Bevor das konkrete Gehäuse konstruiert und gedruckt werden kann, ist ein grundlegendes Verständnis der zugrunde liegenden Fertigungstechnologie notwendig.
Nur wer das Funktionsprinzip, die typischen Grenzen und die Fehlerquellen des Verfahrens kennt, kann ein Bauteil so konstruieren, dass es sich überhaupt fertigen lässt und die geforderten Eigenschaften erfüllt.
Aus diesem Grund wird in diesem Kapitel zunächst das allgemeine Prinzip der additiven Fertigung erläutert und anschließend schrittweise auf das konkret verwendete Verfahren und den eingesetzten Drucker eingegrenzt.

==== Funktionsprinzip der additiven Fertigung

Unter additiver Fertigung – umgangssprachlich _3D-Druck_ – versteht man die Herstellung eines dreidimensionalen Objekts aus einem digitalen Modell, bei der das Material schrittweise hinzugefügt und verbunden wird, typischerweise Schicht für Schicht (vgl. <<wiki-3dprint>>).
Der Begriff steht damit im direkten Gegensatz zur _subtraktiven Fertigung_, dem Sammelbegriff für spanende Verfahren wie Fräsen oder Drehen, deren gemeinsames Merkmal der Materialabtrag aus einem Rohling ist.

Der grundlegende konzeptionelle Unterschied hat weitreichende praktische Folgen.
Bei subtraktiven Verfahren steigt der Aufwand mit der geometrischen Komplexität des Bauteils, weil jede Hinterschneidung und jede Bohrung eigene Werkzeugwege und oft Umspannvorgänge erfordert.
Bei der additiven Fertigung ist die Komplexität der Geometrie hingegen weitgehend "kostenlos", da ohnehin jede Schicht einzeln aufgebaut wird – ein Hohlraum oder eine organisch geformte Wand verursacht prinzipiell keinen Mehraufwand gegenüber einem massiven Quader gleicher Abmessung.
Dafür entstehen andere Einschränkungen, etwa die Notwendigkeit von Stützstrukturen bei Überhängen und eine richtungsabhängige Festigkeit, auf die in den folgenden Abschnitten eingegangen wird.

Die additive Fertigung ist kein einzelnes Verfahren, sondern eine ganze Verfahrensfamilie.
Die Norm ISO/ASTM 52900 fasst die existierenden Technologien in sieben Verfahrensklassen zusammen (vgl. <<iso-52900>>).

.Die sieben Verfahrensklassen der additiven Fertigung nach ISO/ASTM 52900
[cols="1,3",options="header"]
|===
| Verfahrensklasse | Kurzbeschreibung
| Material Extrusion (MEX) | Selektives Ausbringen von Material durch eine Düse – hierzu gehört das in dieser Arbeit verwendete FDM/FFF-Verfahren.
| Vat Photopolymerization (VPP) | Schichtweises Aushärten eines flüssigen Photopolymers mittels Licht (z.B. SLA, DLP).
| Powder Bed Fusion (PBF) | Verschmelzen eines Pulverbetts mit Laser oder Elektronenstrahl (z.B. SLS, SLM).
| Binder Jetting (BJT) | Selektives Einbringen eines Bindemittels in ein Pulverbett.
| Material Jetting (MJT) | Tröpfchenweises Auftragen und Aushärten eines Werkstoffs (vergleichbar dem Tintenstrahldruck).
| Directed Energy Deposition (DED) | Auftragen und gleichzeitiges Aufschmelzen von Material, meist für Metall.
| Sheet Lamination (SHL) | Verbinden und Zuschneiden aufeinandergelegter Materialschichten.
|===

Für ein Gehäuse aus Kunststoff, das in einer Schul- bzw. Hobbyumgebung gefertigt wird, ist die Materialextrusion das mit Abstand wirtschaftlichste und am leichtesten zugängliche Verfahren.
Es benötigt weder gesundheitsgefährdende Harze noch feine Metallpulver und kommt mit vergleichsweise günstigen Geräten aus.

==== Das FDM/FFF-Verfahren

Innerhalb der Materialextrusion ist das _Fused Deposition Modeling_ (FDM) das dominierende Verfahren.
Ein endloser Kunststofffaden, das sogenannte _Filament_, wird von einer Spule abgewickelt, durch einen beheizten Druckkopf geführt, dort aufgeschmolzen und durch eine feine Düse Schicht für Schicht auf die Bauplattform bzw. auf die bereits gedruckten Schichten aufgetragen (vgl. <<wiki-fff>>).
Unmittelbar nach dem Austritt kühlt der Kunststoff ab, erstarrt und verschmilzt dabei mit der darunterliegenden Schicht.

Begrifflich ist eine Unterscheidung wichtig, die in der Literatur häufig synonym verwendet wird.
Der Ausdruck _Fused Deposition Modeling_ wurde von S. Scott Crump, einem Mitgründer der Firma Stratasys, Ende der 1980er-Jahre entwickelt und 1989 patentiert; "FDM" ist bis heute eine eingetragene Marke von Stratasys (vgl. <<wevolver-fdm>>).
Um eine markenrechtlich unbedenkliche Bezeichnung zur Verfügung zu haben, prägten Mitglieder des offenen RepRap-Projekts ab 2005 den gleichbedeutenden Begriff _Fused Filament Fabrication_ (FFF).
Technisch beschreiben beide Abkürzungen denselben Vorgang; in dieser Arbeit wird überwiegend die verbreitete Bezeichnung FDM verwendet.

==== Aufbau und Funktionsweise eines FDM-Druckers

Ein FDM-Drucker besteht im Kern aus wenigen funktionalen Baugruppen, deren Zusammenspiel die Druckqualität bestimmt.

* Der _Extruder_ fördert das feste Filament mit einem angetriebenen Zahnrad in Richtung Druckkopf und erzeugt dort den nötigen Vorschubdruck.
* Das _Hotend_ schmilzt das Filament unmittelbar vor der Düse auf und gibt es durch die typischerweise 0,4 mm große Düsenöffnung ab.
* Das _beheizte Druckbett_ sorgt für die Haftung der ersten Schicht und verringert das Verziehen des Bauteils.
* Das _Bewegungssystem_ positioniert Druckkopf und Bett relativ zueinander in den drei Raumachsen.

Beim Bewegungssystem haben sich unterschiedliche Bauformen etabliert.
Klassische Geräte nach dem _kartesischen_ Prinzip bewegen die Achsen weitgehend unabhängig voneinander, was einfach aufzubauen, aber bei hohen Geschwindigkeiten durch die bewegten Massen begrenzt ist.
Der in diesem Projekt eingesetzte Drucker arbeitet hingegen nach der _CoreXY_-Kinematik, bei der zwei fest montierte Motoren über ein gekreuztes Riemensystem gemeinsam die X- und Y-Bewegung erzeugen (vgl. <<bambu-p2s-wiki>>).
Da die schweren Motoren nicht mitbewegt werden müssen, lassen sich deutlich höhere Geschwindigkeiten und Beschleunigungen bei guter Präzision erreichen.

Für diese Arbeit wurde der Drucker _Bambu Lab P2S_ verwendet.
Es handelt sich um ein CoreXY-Gerät mit vollständig geschlossenem Bauraum, dessen wichtigste Kenndaten in der folgenden Tabelle zusammengefasst sind.

.Technische Eckdaten des verwendeten Druckers Bambu Lab P2S
[cols="2,3",options="header"]
|===
| Merkmal | Wert
| Kinematik | CoreXY
| Bauraum (B × T × H) | 256 × 256 × 256 mm
| Bauraum geschlossen | ja (passiv temperiert, keine aktive Kammerheizung)
| max. Düsentemperatur | 300 °C
| max. Druckbett-Temperatur | 110 °C
| max. Druckgeschwindigkeit | 600 mm/s
| max. Beschleunigung | 20.000 mm/s²
| Standard-Düse | 0,4 mm
| Multimaterial-System | AMS 2 Pro, 4 Filament-Slots
|===

Der geschlossene Bauraum ist für diese Arbeit besonders relevant.
Er hält die Wärme im Inneren, schirmt Zugluft ab und ist damit eine wichtige Voraussetzung, um auch verzugsanfällige Materialien sauber drucken zu können (vgl. <<bambu-p2s-specs>>).
Das angeschlossene _Automatic Material System_ (AMS 2 Pro) erlaubt es zudem, mehrere Filamente bereitzuhalten und automatisch zu wechseln; im konkreten Druck wurde diese Funktion jedoch nur zur Auswahl der aktiven Spule genutzt.

==== Vom 3D-Modell zum Druck: der Slicing-Prozess

Ein 3D-Drucker kann mit einem CAD-Modell nichts unmittelbar anfangen, denn er versteht keine geschlossenen Volumenkörper, sondern nur konkrete Bewegungs- und Extrusionsbefehle.
Die Übersetzung zwischen beiden Welten übernimmt eine spezielle Software, der sogenannte _Slicer_.
Er zerlegt das Modell – meist im STL-Format – in horizontale Schichten und erzeugt daraus _G-Code_, eine Folge von Anweisungen, die dem Drucker für jede Schicht exakt vorgeben, wohin der Druckkopf fährt und wie viel Material er dabei abgibt (vgl. <<natives-bambustudio>>).

Der grundsätzliche Ablauf vom Modell bis zum fertigen Bauteil lässt sich als einfache Prozesskette darstellen.

[plantuml,format=svg]
----
@startuml
skinparam shadowing false
skinparam activity {
  BackgroundColor #EEF5FF
  BorderColor #2C6FB5
}
start
:CAD-Konstruktion;
:Export als STL-Datei;
:Import in den Slicer\n(Bambu Studio);
:Druckparameter wählen\n(Material, Schichthöhe, Infill, Stützen);
:Slicing -> G-Code;
:Übertragung an den Drucker;
:Schichtweiser Druck;
:Nachbearbeitung\n(Stützen entfernen);
stop
@enduml
----

Im vorliegenden Projekt wurde der Slicer _Bambu Studio_ eingesetzt, die auf PrusaSlicer basierende, quelloffene Software des Druckerherstellers (vgl. <<bambu-studio-wiki>>).
Welche konkreten Parameter dabei gewählt wurden und warum, ist Gegenstand des nächsten Hauptkapitels.

==== Schichtaufbau, Haftung und typische Druckfehler

Da ein FDM-Bauteil aus vielen aufeinander verschmolzenen Schichten besteht, ist seine Festigkeit _anisotrop_: in Schichtebene ist es stabiler als senkrecht dazu, weil die Bindung zwischen den Schichten schwächer ist als das Material innerhalb einer Schicht.
Diese Eigenschaft muss bei der Konstruktion mitgedacht werden, indem man die zu erwartende Belastung möglichst in die Schichtebene legt.

Die Qualität eines Drucks hängt entscheidend von der Haftung ab – sowohl der ersten Schicht auf dem Druckbett als auch der Schichten untereinander.
Treten hier Probleme auf, äußern sie sich in charakteristischen Druckfehlern, die in der folgenden Tabelle mit ihren häufigsten Ursachen zusammengefasst sind.

.Typische FDM-Druckfehler und ihre Ursachen
[cols="1,3",options="header"]
|===
| Fehlerbild | Häufige Ursache
| Warping (Verzug) | Schrumpfung beim Abkühlen zieht die Ecken vom Bett hoch; verstärkt bei zu kaltem Bett oder Zugluft (vgl. <<s3d-warping>>).
| Layer-Shifting (Schichtversatz) | Druckkopf zu schnell oder mechanisches Problem wie lose Riemen; Folgeschichten sind seitlich verschoben (vgl. <<s3d-layershift>>).
| Stringing (Fädenbildung) | Austretender Kunststoff bei Leerfahrten durch zu geringe Retraktion oder zu hohe Düsentemperatur (vgl. <<s3d-stringing>>).
| Elephant Foot (Elefantenfuß) | Düse zu nah am Bett, die untersten Schichten werden breitgequetscht (vgl. <<natives-elephant>>).
| Schlechte Schichthaftung | Schichthöhe zu groß oder Drucktemperatur zu niedrig, die Schichten verschmelzen unzureichend (vgl. <<s3d-layersplit>>).
|===

Das Wissen um diese Fehlerbilder ist nicht nur theoretisch relevant.
Wie in <<konstruktion>> gezeigt wird, lässt sich ein Teil der konstruktiven Schwachstellen des ersten Gehäuseentwurfs direkt auf solche fertigungsbedingten Effekte und die geometriebedingte Verzugsneigung zurückführen.

=== Auswahl der Druckparameter und Kunststoffe

Ein gelungenes Druckergebnis ist immer das Resultat zweier eng verzahnter Entscheidungen: der Wahl des _Materials_ und der Wahl der _Druckparameter_.
Beide müssen zu den Anforderungen des konkreten Bauteils passen.
Daher werden in diesem Kapitel zunächst die Anforderungen an das Gehäuse formuliert, anschließend die in Frage kommenden Kunststoffe verglichen und schließlich die einzelnen Parameter begründet, mit denen das Gehäuse tatsächlich gedruckt wurde.

==== Anforderungen an das Gehäuse

Das Gehäuse umschließt die Elektronik des Zeiterfassungsterminals – im Wesentlichen die Platine, den Mikrocontroller und ein NFC-/RFID-Lesefeld.
Daraus ergeben sich mehrere Anforderungen.

* _Schutz_: Die Elektronik muss gegen mechanische Beschädigung und versehentliche Berührung geschützt sein.
* _Zugänglichkeit_: Der Deckel soll sich für Wartung und Reparatur zerstörungsfrei öffnen und wieder verschließen lassen.
* _Funktionsfähigkeit der Sensorik_: Das NFC-Lesefeld muss nahe der Oberfläche liegen, da das Magnetfeld nur eine geringe Reichweite besitzt; über dem Lesefeld darf kein metallisches Material und nur eine dünne Kunststoffwand liegen.
* _Maßhaltigkeit_: Aussparungen für Anschlüsse und das Display müssen passgenau sitzen.
* _Robustheit im Alltag_: Da das Terminal regelmäßig benutzt wird, müssen vor allem der Verschlussmechanismus und die Kanten eine gewisse Schlagzähigkeit aufweisen.
* _Temperaturtoleranz_: Das Gehäuse soll sich durch die Abwärme der Elektronik und durch Umgebungswärme nicht verformen.

Insbesondere die Forderungen nach Schlagzähigkeit und Temperaturtoleranz schließen einige sonst beliebte Materialien faktisch aus, wie der folgende Vergleich zeigt.

==== Vergleich gängiger Kunststoffe (PLA, PETG, ASA)

Für den FDM-Druck stehen zahlreiche Thermoplaste zur Verfügung.
Für ein Funktionsgehäuse sind in der Praxis vor allem drei Materialien relevant: PLA, PETG und ASA.
Sie unterscheiden sich deutlich in Druckbarkeit, mechanischen Eigenschaften und Beständigkeit.

.Vergleich der Kunststoffe PLA, PETG und ASA
[cols="2,2,2,2",options="header"]
|===
| Eigenschaft | PLA | PETG | ASA
| Düsentemperatur | 190–220 °C | 230–250 °C | 240–260 °C
| Druckbett-Temperatur | 45–60 °C | 75–90 °C | 90–110 °C
| Glasübergangstemperatur | ~60 °C | ~80–85 °C | ~100–105 °C
| Mechanik | steif, aber spröde | zäh, schlagzäh, leicht flexibel | sehr schlag- und verschleißfest
| UV-/Witterungsbeständigkeit | gering | gut | sehr gut
| Verzugsneigung (Warping) | gering | gering | hoch
| Emissionen beim Druck | gering | sehr gering | Styroldämpfe, Absaugung empfohlen
| Geschlossener Bauraum nötig | nein | nein | praktisch ja
| Typische Anwendung | Prototypen, Deko | Funktionsteile, Gehäuse | Außen-/Kfz-Teile
|===

Die Werte beruhen auf den Materialdatenblättern und Hersteller-Empfehlungen (vgl. <<prusa-pla>>, <<prusa-petg>>, <<prusa-asa>>, <<simplify-petg>>).
PLA ist am einfachsten zu drucken, aber spröde und mit einer Glasübergangstemperatur von nur etwa 60 °C wenig wärmebeständig – es kann sich bereits in einem in der Sonne stehenden Auto verformen.
ASA bietet die besten mechanischen und Witterungseigenschaften, neigt jedoch stark zum Verziehen, setzt beim Druck Styroldämpfe frei und verlangt einen geschlossenen, möglichst beheizten Bauraum.
PETG positioniert sich zwischen diesen Polen.

==== Begründung der Materialwahl

Für das Gehäuse fiel die Wahl auf _PETG_.

PETG gilt als guter Kompromiss zwischen der einfachen Druckbarkeit von PLA und der Robustheit technischer Kunststoffe wie ABS oder ASA (vgl. <<ultimaker-compare>>).
Es ist zäh und leicht flexibel statt spröde, sodass der für ein Gehäuse kritische Verschlussmechanismus nicht sofort bricht, sondern Belastungen elastisch aufnehmen kann.
Mit einer Glasübergangstemperatur von rund 80 °C ist es deutlich wärmebeständiger als PLA und übersteht die Abwärme der Elektronik problemlos (vgl. <<prusa-petg>>).
Gleichzeitig zeigt es – anders als ASA – nur eine geringe Verzugsneigung und lässt sich nahezu geruchsfrei und ohne zwingende Absaugung verarbeiten.

Eine Verwendung von ASA wäre aus Sicht der mechanischen und thermischen Eigenschaften ebenfalls denkbar gewesen und hätte zusätzlich eine sehr gute UV-Beständigkeit für den Außeneinsatz geboten.
Da das Terminal jedoch im Innenraum betrieben wird, die hohe Warping-Neigung von ASA gerade bei der flächigen Grundplatte des Gehäuses Probleme bereitet hätte und PETG die geforderte Schlagzähigkeit bereits sicher erfüllt, wurde PETG als bestmöglicher Kompromiss aus Robustheit, Druckbarkeit und Sicherheit gewählt.

In den folgenden Abschnitten werden die einzelnen Slicer-Parameter erläutert, die für diesen Druck verwendet wurden.
Die Werte stammen aus dem dokumentierten Druckauftrag des Projekts (Profil _0,20 mm Standard @BBL P2S_).

==== Schichthöhe und Auflösung

Die Schichthöhe bestimmt die vertikale Auflösung und damit den sichtbaren Treppenstufeneffekt an schrägen Flächen sowie die Druckdauer.
Als grobe Faustregel sollte die Schichthöhe etwa 25 % bis maximal 75–80 % des Düsendurchmessers betragen (vgl. <<prusa-layers>>).
Bei der verwendeten 0,4-mm-Düse ist eine Schichthöhe von 0,20 mm daher ein bewährter Mittelwert zwischen Oberflächenqualität und Geschwindigkeit.

.Auswahl des Druckprofils in Bambu Studio
[#fig-slicer-profil]
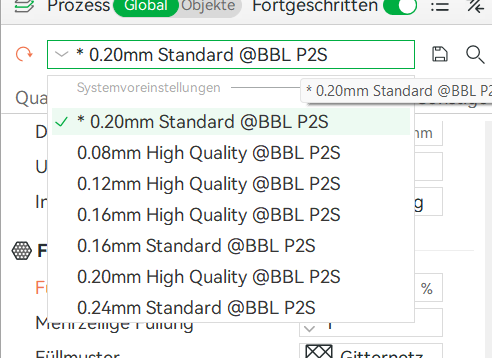
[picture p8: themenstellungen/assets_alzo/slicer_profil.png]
Druckprofile im Slicer


Für ein zweckmäßiges Gehäuse ohne hohe optische Ansprüche wäre auch ein gröberes Profil mit 0,24 mm oder 0,28 mm vertretbar gewesen, was die Druckzeit verkürzt hätte.
Umgekehrt hätten feinere Profile bis 0,08 mm die Oberfläche verbessert, aber die Druckdauer vervielfacht – ein für ein Funktionsbauteil unnötiger Aufwand.
Das gewählte Standardprofil von 0,20 mm stellt den praxisüblichen Kompromiss dar.

==== Fülldichte und Füllmuster (Infill)

Das Innere eines gedruckten Bauteils ist in der Regel nicht massiv, sondern wird mit einem regelmäßigen Gitter, dem _Infill_, ausgefüllt.
Die _Fülldichte_ gibt an, wie viel Prozent des Innenvolumens tatsächlich mit Material gefüllt werden; das _Füllmuster_ bestimmt die geometrische Anordnung dieses Materials.

Eine höhere Fülldichte erhöht Festigkeit und Gewicht, verlängert aber Druckzeit und Materialverbrauch.
In der Praxis genügen für die meisten Bauteile 10–15 %, da die Festigkeit eines Modells überwiegend von den Außenwänden und nicht vom Infill bestimmt wird (vgl. <<prusa-infill>>).
Für das Gehäuse wurde eine Fülldichte von 10 % mit einem Gitternetz-Muster gewählt.

.Einstellung von Fülldichte und Füllmuster im Slicer
[#fig-slicer-staerke]
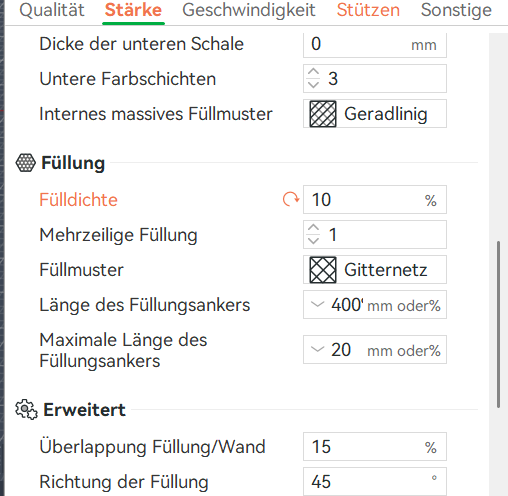
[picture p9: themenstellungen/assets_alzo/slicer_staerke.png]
Stärke-Einstellungen mit 10% Gitternetz-Infill


Diese Wahl ist für ein Gehäuse sinnvoll: Es trägt keine hohen Lasten, sondern muss vor allem formstabil sein und die Elektronik umschließen.
Ein höherer Infill von beispielsweise 30 % hätte das Gewicht und die Druckzeit unnötig erhöht, ohne einen funktionalen Vorteil zu bringen.

==== Wand- und Bodenstärke

Während das Infill das Innere füllt, bestimmen die _Wandstärke_ (Anzahl der äußeren Umrandungen, der sogenannten Perimeter) und die Anzahl der _Boden- und Deckschichten_ die tatsächliche Festigkeit und Dichtigkeit der Außenhülle.
Gerade weil die Festigkeit eines FDM-Bauteils stärker von den Perimetern als vom Infill abhängt, ist eine ausreichende Wandstärke für ein robustes Gehäuse entscheidend (vgl. <<prusa-layers>>).

Im Druckauftrag waren drei untere Schichten (Bodenlagen) eingestellt.
In Kombination mit mehreren Perimetern entsteht so eine geschlossene, tragfähige Außenhülle, die das vergleichsweise dünne 10-%-Infill umschließt und dem Bauteil seine Steifigkeit gibt.
Für ein Gehäuse mit dünner Wand über dem NFC-Lesefeld ist dieser Aufbau ideal, weil die tragende Funktion von den Wänden übernommen wird und das Lesefenster trotzdem dünn bleiben kann.

==== Temperaturführung (Düse, Druckbett, Kammer)

Die Verarbeitungstemperaturen müssen exakt zum Material passen.
Eine zu niedrige Düsentemperatur führt zu schlechter Schichthaftung, eine zu hohe zu Fädenbildung und Verbrennungen; ein zu kaltes Bett verursacht Verzug.

Für den PETG-Druck wurden gemäß Projektdokumentation folgende Temperaturen verwendet.

* _Düsentemperatur_: 255 °C
* _Druckbett-Temperatur_: 70 °C
* _Kammertemperatur_: rund 41 °C (passiv, durch den geschlossenen Bauraum)

Diese Werte liegen genau im empfohlenen Bereich für PETG und nutzen den geschlossenen Bauraum des P2S aus, ohne dass eine aktive Kammerheizung nötig wäre.
Die passiv erhöhte Kammertemperatur stabilisiert die Schichthaftung und reduziert Spannungen im Bauteil.
Bei PLA wären deutlich niedrigere Temperaturen (etwa 210 °C Düse, 60 °C Bett) gewählt worden, bei ASA hingegen höhere Werte und eine möglichst warme Kammer.

==== Stützstrukturen und Überhänge

Da jede Schicht auf der darunterliegenden aufliegen muss, kann ein FDM-Drucker Überhänge nur bis zu einem gewissen Winkel "in die Luft" drucken.
Steilere Überhänge oder freistehende Bauteilbereiche benötigen temporäre _Stützstrukturen_, die nach dem Druck wieder entfernt werden (vgl. <<prusa-support>>).

Im Druckauftrag wurden Stützstrukturen vom Typ _Baum (auto)_ mit einem Schwellenwinkel von 30° aktiviert.

.Einstellung der Stützstrukturen im Slicer
[#fig-slicer-stuetzen]
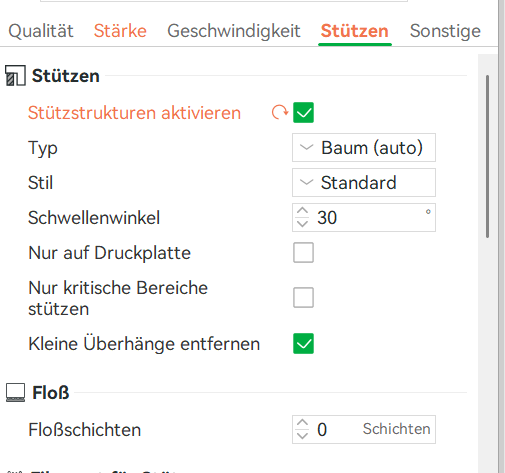
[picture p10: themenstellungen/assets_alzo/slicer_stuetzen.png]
Baumförmige Stützstrukturen mit 30 Grad Schwellenwinkel


Baumförmige Stützen verbrauchen weniger Material als klassische gitterförmige Stützen und lassen sich meist leichter ablösen.
Der geringe Stützenanteil von nur 0,64 g am Gesamtgewicht von rund 95 g zeigt, dass das Gehäuse weitgehend stützenarm konstruiert wurde – ein Zeichen für ein druckgerechtes Design, bei dem große Überhänge bewusst vermieden wurden.

==== Druckhaftung und Plattenauswahl

Die erste Schicht entscheidet maßgeblich über den Erfolg des gesamten Drucks, denn löst sich das Bauteil während des Drucks vom Bett, ist der Druck verloren.
Zur Verbesserung der Haftung stehen im Slicer Hilfsmittel wie _Skirt_ (eine vorgelagerte Umrandung zur Stabilisierung des Materialflusses), _Brim_ (ein verbreiteter Rand um die erste Schicht) und _Raft_ (eine mehrlagige Grundplatte) zur Verfügung (vgl. <<prusa-skirt>>).

Im vorliegenden Druck wurde bewusst _ohne Raft_ (Floß: 0 Schichten) gedruckt.
Als Druckunterlage diente die _Bambu Textured PEI Plate_, deren strukturierte Oberfläche bei PETG für eine zuverlässige Haftung sorgt und gleichzeitig der Unterseite des Bauteils eine angenehme, matte Textur verleiht.
Da PETG ohnehin nur gering zum Verzug neigt, war auf der temperierten PEI-Platte weder ein Raft noch ein Brim erforderlich, was Materialverbrauch und Nacharbeit weiter reduziert.

[#konstruktion]
=== Konstruktion und Prüfung des Gehäuses

Nach der Festlegung von Material und Druckparametern folgt die eigentliche Konstruktion.
Charakteristisch für die Produktentwicklung ist, dass selten der erste Entwurf bereits optimal ist.
Dieses Kapitel dokumentiert daher bewusst den iterativen Weg über zwei Designvarianten und macht damit den Erkenntnisgewinn zwischen erstem und zweitem Entwurf nachvollziehbar.

==== Konstruktionsanforderungen der Hardware

Aus den zuvor formulierten allgemeinen Anforderungen ergeben sich konkrete konstruktive Vorgaben.
Das Gehäuse ist zweiteilig aufgebaut und besteht aus einem _Unterteil_, das die Platine aufnimmt, und einem _Deckel_, der das Gehäuse verschließt.

* Das Unterteil besitzt _Standoffs_ (Abstandshalter mit Bohrungen), auf denen die Platine verschraubt bzw. eingesetzt wird, sodass sie nicht direkt auf dem Boden aufliegt.
* Der Deckel trägt eine rechteckige Aussparung für das Display bzw. das Anzeigefenster sowie eine eingeprägte NFC-Markierung, die dem Benutzer die Position des Lesefeldes anzeigt.
* Die Grundfläche beträgt etwa 96 × 96 mm.
* Deckel und Unterteil sollen ohne Schrauben über einen Schnappverschluss zusammengehalten werden, um das Öffnen werkzeuglos zu ermöglichen.

Gerade der letzte Punkt – ein zuverlässiger, werkzeugloser Schnappverschluss – erwies sich als die zentrale konstruktive Herausforderung.

==== Erste Konstruktion (Design 1)

Der erste Entwurf setzt den zweiteiligen Aufbau direkt um.
Das Unterteil ist eine offene Wanne mit umlaufender Wand und integrierten Standoffs; der Deckel ist eine flache Platte mit Display-Aussparung und NFC-Prägung.

.Design 1 – Unterteil mit Standoffs
[#fig-design1-unten]
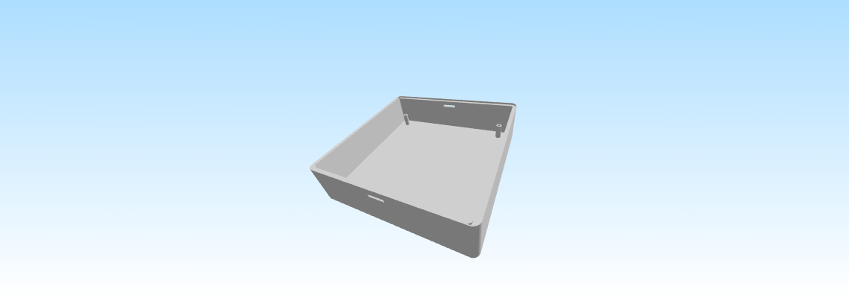
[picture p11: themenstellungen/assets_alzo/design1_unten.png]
Unterteil des ersten Gehäuseentwurfs


.Design 1 – Deckel mit NFC-Prägung
[#fig-design1-deckel]
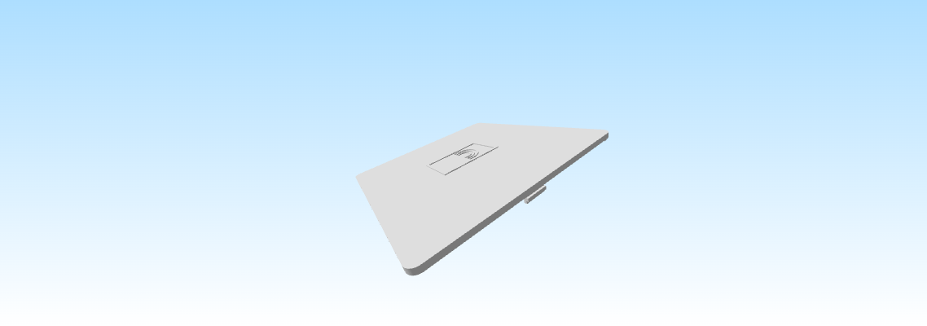
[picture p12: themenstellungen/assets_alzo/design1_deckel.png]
Deckel des ersten Gehäuseentwurfs


Der Deckel wird bei diesem Entwurf ausschließlich über zwei schmale Schnapp-Laschen an der Vorder- und der Rückseite gehalten.
An den beiden Seitenwänden gibt es keine Verriegelung.
Dieser Aufbau ist einfach und materialsparend, weist aber gravierende Schwächen auf, die erst in der praktischen Erprobung deutlich zutage traten.

==== Konstruktive Schwachstellen des Schnappverschlusses

Die Erprobung des ersten Gehäuses offenbarte zwei wesentliche, miteinander zusammenhängende Probleme.

Erstens fehlt aufgrund der nur an zwei Punkten angebrachten Verriegelung in der Mitte der Seitenwände jeglicher Gegenhalt.
Bei der Gehäusegröße von rund 96 × 96 mm biegt sich der Deckel dort nach oben und schließt nicht mehr bündig ab – es entsteht ein sichtbarer Spalt an den Seiten.
Dies ist eine unmittelbare Folge der großen, nur an den Enden gestützten Spannweite und wird durch die geringe Eigensteifigkeit der dünnen Deckelplatte verstärkt.

Zweitens sind die Schnapphaken mit nur 0,9 mm Materialstärke sehr filigran ausgeführt.
In Verbindung mit dem schichtweisen Aufbau des FDM-Drucks, bei dem die Schichtgrenzen Sollbruchstellen quer zur Belastung darstellen, sind die Haken äußerst zerbrechlich.
Beim wiederholten Öffnen und Schließen brechen sie leicht ab, und die Verrastung nutzt sich bereits nach wenigen Benutzungen sichtbar ab.

Zusammengefasst krankte das erste Design an _zu wenigen, zu dünnen und ungleichmäßig verteilten_ Schnapppunkten.
Die Schwachstellen sind damit nicht primär ein Fertigungs-, sondern ein Konstruktionsproblem, das nur durch eine Überarbeitung der Geometrie zu beheben war.

==== Überarbeitete Konstruktion (Design 2)

Im zweiten Entwurf wurde der Verschluss grundlegend neu gestaltet.
Statt nur zweier punktueller Laschen ist der Verschluss nun gleichmäßig über den gesamten Gehäuseumfang verteilt.

.Design 2 – zusammengesetztes Gehäuse
[#fig-design2-case]
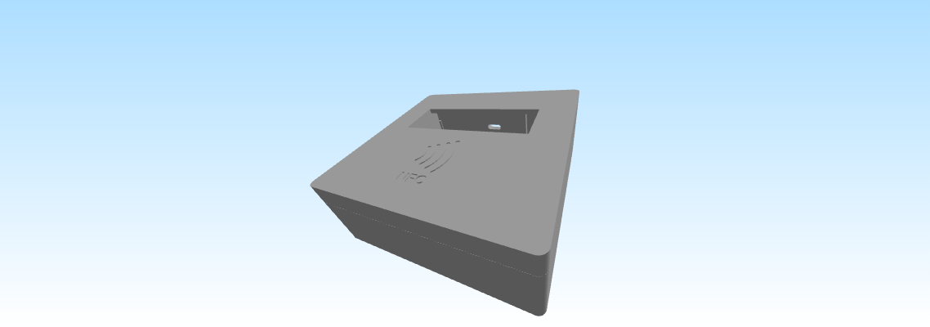
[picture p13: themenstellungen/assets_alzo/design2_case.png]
Zusammengesetztes Gehäuse des zweiten Entwurfs


.Design 2 – überarbeitetes Unterteil
[#fig-design2-unten]
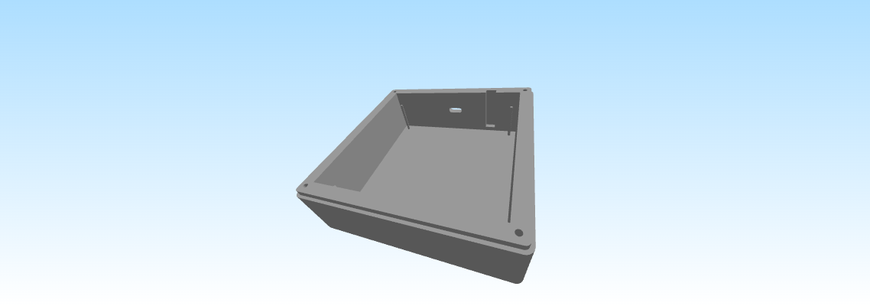
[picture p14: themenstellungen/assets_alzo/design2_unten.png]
Unterteil des zweiten Gehäuseentwurfs


.Design 2 – überarbeiteter Deckel
[#fig-design2-deckel]
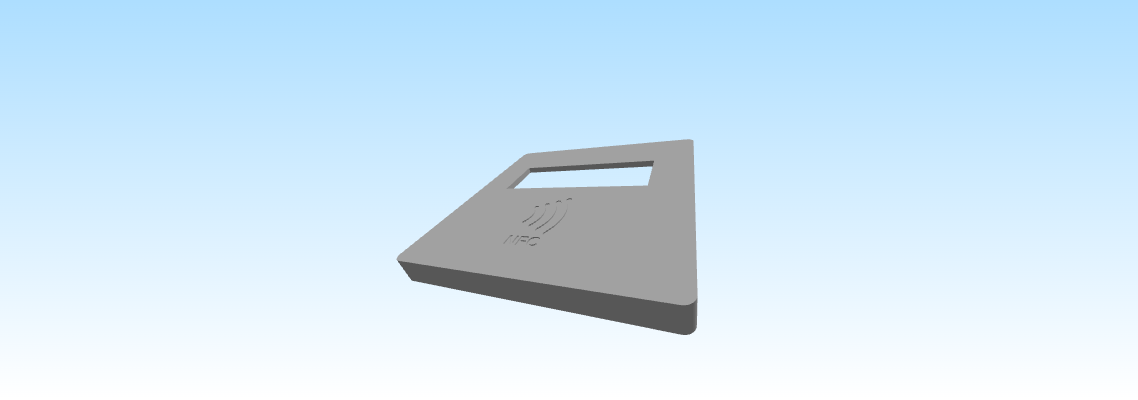
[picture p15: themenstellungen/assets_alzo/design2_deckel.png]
Deckel des zweiten Gehäuseentwurfs


Durch die umlaufende Verteilung des Verschlusses liegt der Deckel an allen Seiten gleichmäßig auf.
Der zuvor störende Spalt an den Seitenwänden entfällt, weil die Mitte der langen Seiten nun ebenfalls gehalten wird.
Der Schließdruck verteilt sich gleichmäßiger auf viele Kontaktstellen, sodass die einzelne Verbindung weniger stark belastet wird und die gesamte Mechanik robuster und weniger bruchanfällig ist.

==== Vergleich und Bewertung beider Gehäuse

Die folgende Tabelle stellt die beiden Entwürfe einander gegenüber.

.Gegenüberstellung von Design 1 und Design 2
[cols="2,2,2",options="header"]
|===
| Kriterium | Design 1 | Design 2
| Verschlussprinzip | 2 punktuelle Laschen (vorne/hinten) | umlaufend verteilte Verriegelung
| Anliegen des Deckels | Spalt an den Seiten | überall bündig
| Schließdruck | ungleichmäßig, auf 2 Punkte konzentriert | gleichmäßig verteilt
| Bruchgefahr der Haken | hoch (0,9 mm, filigran) | deutlich reduziert
| Wiederholtes Öffnen/Schließen | Verrastung nutzt sich schnell ab | dauerhaft stabiler
| Bewertung | funktional, aber nicht alltagstauglich | alltagstaugliche Lösung
|===

Der Vergleich zeigt exemplarisch ein zentrales Prinzip druckgerechten Konstruierens: Belastungen sollten auf möglichst viele, ausreichend dimensionierte Kontaktstellen verteilt werden, statt sie an wenigen filigranen Punkten zu konzentrieren.
Damit erfüllt Design 2 die eingangs formulierten Anforderungen an Robustheit und Zugänglichkeit, die Design 1 verfehlt hatte.

==== Druckergebnis und Funktionsprüfung

Das überarbeitete Gehäuse wurde mit den zuvor beschriebenen Parametern auf dem Bambu Lab P2S gedruckt.
Beide Bauteile – Unterteil und Deckel – wurden gemeinsam auf der Druckplatte angeordnet.

.Anordnung der Bauteile auf der Druckplatte (Generic PETG)
[#fig-slicer-platte]
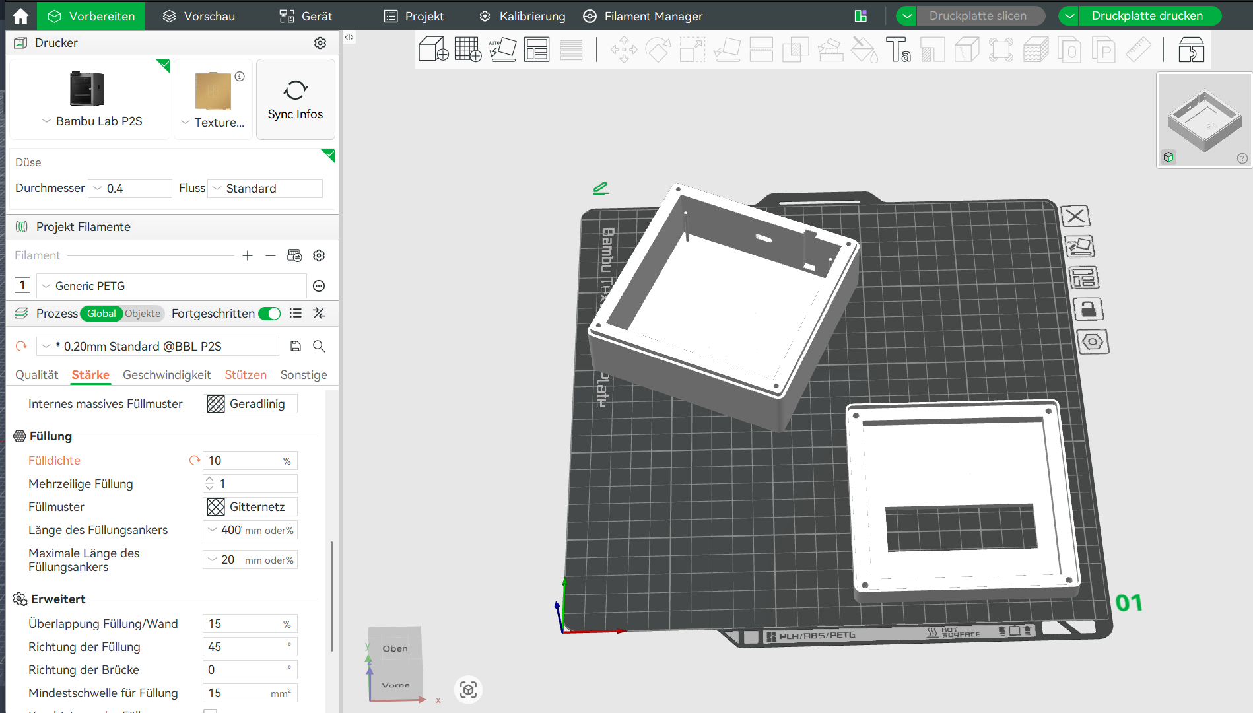
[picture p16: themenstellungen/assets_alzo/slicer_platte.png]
Unterteil und Deckel auf der Druckplatte


Das Slicing ergab folgende Eckdaten für den Druckauftrag _patrick-case_.

.Kenndaten des Druckauftrags
[cols="2,2",options="header"]
|===
| Größe | Wert
| Material | PETG (Generic PETG)
| Schichten gesamt | 165
| Modelldruckzeit | ca. 3 h 1 min
| Materialverbrauch | 94,86 g (Modell 94,21 g + Stützen 0,64 g)
| Filamentlänge | 31,05 m
| Materialkosten | ca. 2,85 €
| Druckplatte | Bambu Textured PEI Plate
|===

.Slicing-Ergebnis mit Zeit-, Material- und Kostenabschätzung
[#fig-slicer-ergebnis]
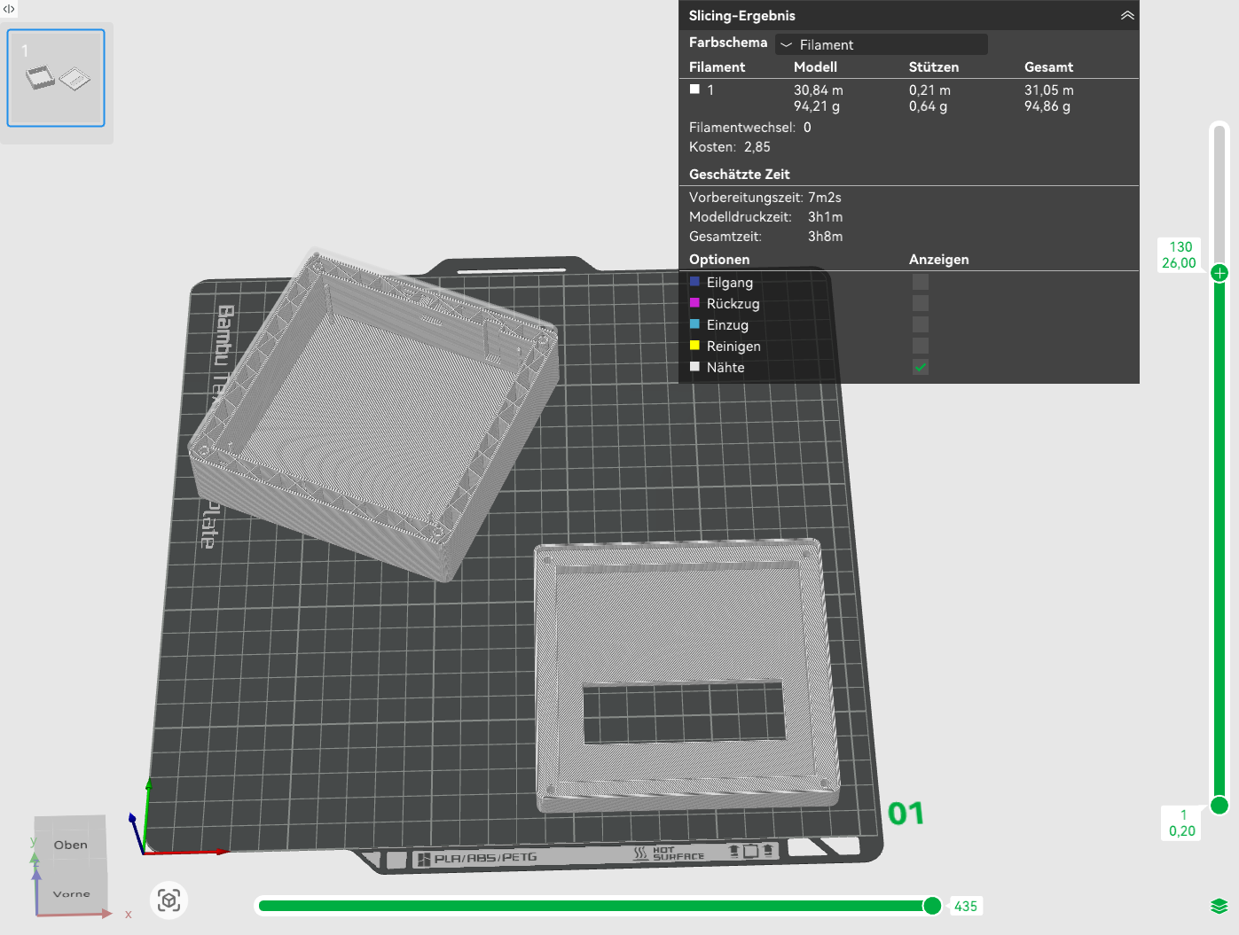
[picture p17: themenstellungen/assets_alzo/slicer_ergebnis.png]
Vorschau und Kennzahlen des Slicing-Ergebnisses


Während des Drucks ließ sich der Fortschritt über die integrierte Kamera und die Statusanzeige des Druckers überwachen.

.Statusüberwachung des laufenden Drucks
[#fig-slicer-status]
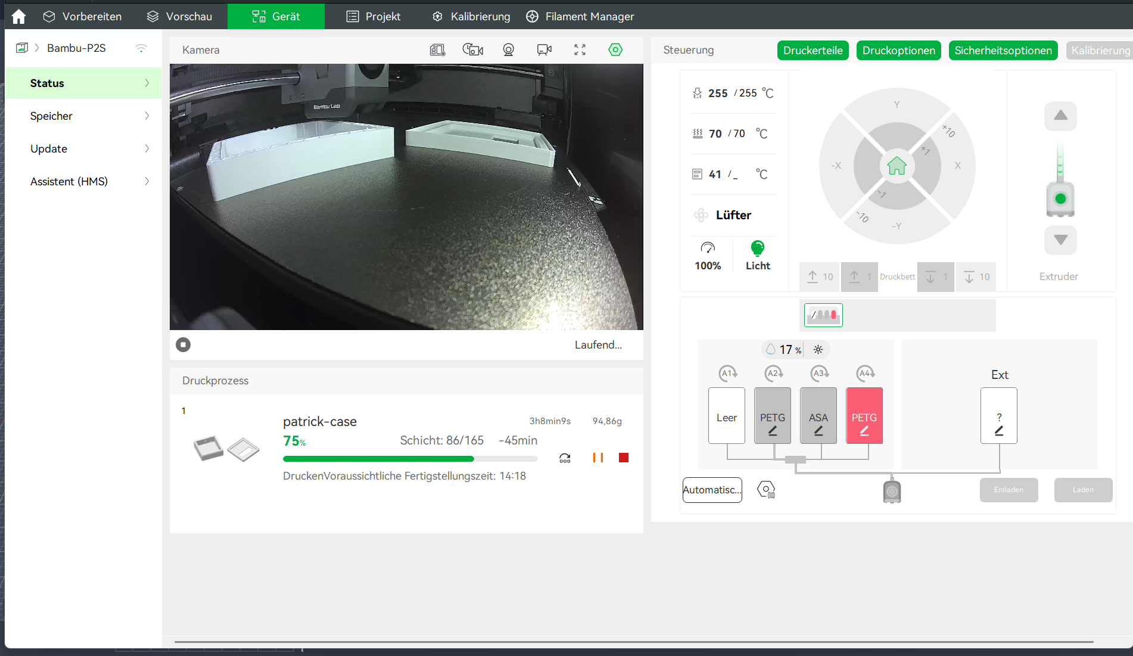
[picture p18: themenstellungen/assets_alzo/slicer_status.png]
Statusanzeige des Druckers während des Drucks


In der abschließenden Funktionsprüfung erfüllte das gedruckte Gehäuse seine Aufgaben.
Der Deckel ließ sich werkzeuglos schließen und wieder öffnen, lag dank des umlaufenden Verschlusses bündig auf und zeigte keinen Spalt mehr.
Die Display-Aussparung und die Standoffs für die Platine passten maßhaltig, und die dünne Wand über dem NFC-Feld beeinträchtigte die Lesefunktion nicht.
Damit ist der konstruktive Teil der Aufgabenstellung – Konstruktion, Druck und Prüfung eines selbst entworfenen Gehäuses – erfolgreich abgeschlossen.

=== Datenbankschema der Applikation

Der zweite Schwerpunkt dieser Arbeit ist die Datenbank, in der sämtliche Arbeitszeitdaten dauerhaft gespeichert werden.
Eine durchdachte Datenbankstruktur ist die Grundlage jeder datengetriebenen Anwendung, weil sich Fehler im Datenmodell später nur mit großem Aufwand korrigieren lassen.
Daher wird das Schema zunächst anhand der fachlichen Anwendungsfälle geplant, anschließend in seiner technischen Umsetzung beschrieben und schließlich getestet und validiert.

==== Planung des Datenmodells anhand von Use Cases

Am Anfang der Datenmodellierung steht die Frage, _welche_ Informationen die Anwendung überhaupt verarbeiten muss.
Diese ergeben sich aus den Anwendungsfällen (Use Cases) des Systems.
Im Zeiterfassungssystem _TimeCortex_ treten drei Rollen auf – Mitarbeiter, Manager und Administrator – mit unterschiedlichen Aufgaben.

[plantuml,format=svg]
----
@startuml
left to right direction
skinparam shadowing false
skinparam packageStyle rectangle

actor Mitarbeiter as MA
actor Manager as MG
actor Administrator as AD

rectangle "Zeiterfassungssystem" {
  usecase "Kommen/Gehen buchen" as UC1
  usecase "Pause erfassen" as UC2
  usecase "Abwesenheit beantragen" as UC3
  usecase "Eigene Zeiten einsehen" as UC4
  usecase "Abwesenheiten genehmigen" as UC5
  usecase "Berichte erzeugen" as UC6
  usecase "Benutzer verwalten" as UC7
  usecase "Anstellungsart pflegen" as UC8
}

MA --> UC1
MA --> UC2
MA --> UC3
MA --> UC4
MG --> UC5
MG --> UC6
AD --> UC5
AD --> UC6
AD --> UC7
AD --> UC8
@enduml
----

Aus diesen Anwendungsfällen lassen sich die benötigten Datenobjekte ableiten.

* Aus _Kommen/Gehen buchen_ folgt die Notwendigkeit, pro Mitarbeiter und Tag eine _Anwesenheitsaufzeichnung_ mit Start- und Endzeit zu speichern.
* Aus _Pause erfassen_ folgt eine eigene Entität für _Pausen_, die einer Anwesenheitsaufzeichnung zugeordnet sind.
* Aus _Abwesenheit beantragen/genehmigen_ folgt eine Entität für _Abwesenheiten_ inklusive Status und Typ (Urlaub, Krank usw.).
* Aus der Rollen- und Rechteverwaltung folgen Entitäten für _Benutzer_, deren _Profile_ (mit Rolle) und die _Login-Daten_.
* Aus _Anstellungsart pflegen_ folgen die _Anstellungsarten_ mit Soll-Arbeitszeit sowie ein _Verlauf_, der Änderungen über die Zeit nachvollziehbar macht.
* Hinzu kommen unterstützende Entitäten für _Feiertage_, _Benachrichtigungen_, _Berichte_, _Wartungsprotokolle_ und _Passwort-Reset-Anträge_.

Eine bewusste Entwurfsentscheidung ist die Trennung von _Benutzer_, _Benutzerprofil_ und _Login-Daten_ in drei Tabellen.
Diese Aufteilung folgt dem Prinzip der Single Responsibility auf Datenebene: identitätsstiftende Stammdaten, organisatorische Profildaten und sicherheitsrelevante Anmeldedaten werden getrennt gehalten.
So kann etwa ein Mitarbeiter im System angelegt sein (Stammdaten), bevor er sich überhaupt registriert hat und dadurch Login-Daten besitzt – ein Umstand, den die Registrierung weiter unten gezielt ausnutzt.

==== Realisiertes physisches Schema

Aus dem konzeptionellen Modell wurde ein physisches Schema in Form einer MariaDB-/MySQL-Datenbank mit der Speicher-Engine _InnoDB_ abgeleitet.
InnoDB wurde gewählt, weil sie als einzige der gängigen MySQL-Engines _Fremdschlüssel_ und _Transaktionen_ unterstützt und damit die referenzielle Integrität auf Datenbankebene durchsetzen kann.
Das folgende Diagramm zeigt die zentralen Tabellen und ihre Beziehungen.

[plantuml,format=svg]
----
@startuml
skinparam shadowing false
skinparam linetype ortho
hide circle

entity benutzer {
  * benutzer_id : INT <<PK>>
  --
  name : VARCHAR
  email : VARCHAR
  nfc_karte_id : VARCHAR
}

entity login_daten {
  * login_id : INT <<PK>>
  --
  benutzer_id : INT <<FK>>
  benutzername : VARCHAR
  passwort_hash : VARCHAR
}

entity benutzerprofile {
  * profil_id : INT <<PK>>
  --
  benutzer_id : INT <<FK>>
  rolle : ENUM
  anstellungs_art_id : INT
}

entity anstellungsarten {
  * art_id : INT <<PK>>
  --
  bezeichnung : VARCHAR
  soll_stunden_pro_tag : TIME
}

entity anstellungsart_verlauf {
  * verlauf_id : INT <<PK>>
  --
  benutzer_id : INT
  anstellungs_art_id : INT
  gueltig_ab : DATE
}

entity anwesenheitsaufzeichnungen {
  * anwesenheit_id : INT <<PK>>
  --
  benutzer_id : INT <<FK>>
  anwesenheits_datum : DATE
  start_arbeitszeit : TIME
  ende_arbeitszeit : TIME
}

entity pausen {
  * pause_id : INT <<PK>>
  --
  benutzer_id : INT <<FK>>
  anwesenheit_id : INT <<FK>>
  start_pause : DATETIME
  ende_pause : DATETIME
}

entity abwesenheiten {
  * abwesenheit_id : INT <<PK>>
  --
  benutzer_id : INT <<FK>>
  abwesenheit_typ : ENUM
  status : ENUM
}

benutzer ||--|| login_daten
benutzer ||--|| benutzerprofile
benutzer ||--o{ anwesenheitsaufzeichnungen
benutzer ||--o{ abwesenheiten
benutzer ||--o{ anstellungsart_verlauf
anwesenheitsaufzeichnungen ||--o{ pausen
anstellungsarten ||--o{ benutzerprofile
@enduml
----

Die Tabelle `benutzer` bildet den Kern des Schemas; nahezu alle übrigen Tabellen verweisen über eine `benutzer_id` auf sie.
Die folgende Anweisung zeigt exemplarisch die Definition der Tabelle `anwesenheitsaufzeichnungen`, in der die eigentlichen Arbeitszeiten gespeichert werden.

.Tabellendefinition der Arbeitszeit-Aufzeichnungen
[source,sql]
----
CREATE TABLE `anwesenheitsaufzeichnungen` (
  `anwesenheit_id`     int(11) NOT NULL,                 -- <1>
  `benutzer_id`        int(11) DEFAULT NULL,             -- <2>
  `anwesenheits_datum` date NOT NULL,                    -- <3>
  `start_arbeitszeit`  time NOT NULL,
  `ende_arbeitszeit`   time NOT NULL,
  `stunden_differenz`  time DEFAULT NULL                 -- <4>
) ENGINE=InnoDB DEFAULT CHARSET=utf8mb4;

ALTER TABLE `anwesenheitsaufzeichnungen`
  ADD PRIMARY KEY (`anwesenheit_id`),                    -- <5>
  ADD KEY `benutzer_id` (`benutzer_id`);                 -- <6>

ALTER TABLE `anwesenheitsaufzeichnungen`
  ADD CONSTRAINT `anwesenheitsaufzeichnungen_ibfk_1`
  FOREIGN KEY (`benutzer_id`)
  REFERENCES `benutzer` (`benutzer_id`);                 -- <7>
----

<1> Künstlicher Primärschlüssel (Surrogate Key), der jede Aufzeichnung eindeutig identifiziert.
<2> Fremdschlüsselspalte, die den Datensatz einem Benutzer zuordnet.
<3> Datum des Arbeitstages; zusammen mit `benutzer_id` identifiziert es einen Arbeitstag fachlich.
<4> Vorberechnete Netto-Differenz, die das spätere Auslesen vereinfacht.
<5> Festlegung des Primärschlüssels.
<6> Index auf der Fremdschlüsselspalte beschleunigt das Filtern nach Benutzer.
<7> Fremdschlüssel-Constraint erzwingt, dass nur existierende Benutzer referenziert werden können.

Eine besonders saubere Modellierung zeigt die Pausen-Tabelle, deren Fremdschlüssel mit der Option `ON DELETE CASCADE` definiert sind.

.Fremdschlüssel der Pausen mit kaskadierendem Löschen
[source,sql]
----
ALTER TABLE `pausen`
  ADD CONSTRAINT `pausen_ibfk_1` FOREIGN KEY (`benutzer_id`)
    REFERENCES `benutzer` (`benutzer_id`) ON DELETE CASCADE,          -- <1>
  ADD CONSTRAINT `pausen_ibfk_2` FOREIGN KEY (`anwesenheit_id`)
    REFERENCES `anwesenheitsaufzeichnungen` (`anwesenheit_id`)
    ON DELETE CASCADE;                                                 -- <2>
----

<1> Wird ein Benutzer gelöscht, werden automatisch alle zugehörigen Pausen mitgelöscht.
<2> Wird eine Anwesenheitsaufzeichnung gelöscht, verschwinden auch deren Pausen – verwaiste Datensätze können so nicht entstehen.

Diese Kaskadierung verhindert _Dateninkonsistenzen_: Es kann keine Pause geben, die auf einen nicht mehr existierenden Arbeitstag verweist.
Die Verantwortung für die referenzielle Integrität liegt damit in der Datenbank selbst und nicht im Anwendungscode, was Fehler durch vergessene Lösch-Logik im PHP-Code ausschließt.

==== Test und Validierung des Schemas

Ein Datenbankschema gilt erst dann als gesichert, wenn es mit realistischen Daten und realen Abfragen geprüft wurde.
Die Validierung erfolgte auf mehreren Ebenen.

Erstens wurde das Schema mit umfangreichen _Testdaten_ befüllt.
Die Datenbank enthält über mehrere Monate generierte Anwesenheitsaufzeichnungen für mehrere Mitarbeiter, dazugehörige Pausen, Abwesenheiten verschiedener Typen sowie Feiertage für zwei Jahre.
Diese Datenmenge stellt sicher, dass die Abfragen nicht nur an wenigen Idealdatensätzen, sondern unter praxisnahen Bedingungen funktionieren.

Zweitens wurde die _referenzielle Integrität_ getestet, indem geprüft wurde, ob die Fremdschlüssel-Constraints fehlerhafte Operationen tatsächlich verhindern.
Der Versuch, eine Pause für eine nicht existierende Anwesenheitsaufzeichnung anzulegen, wird von InnoDB mit einem Fehler abgewiesen; das Löschen eines Arbeitstags entfernt dank `ON DELETE CASCADE` automatisch dessen Pausen.

Drittens wurden die _fachlichen Abfragen_ der Anwendung gegen das Schema ausgeführt.
Eine zentrale Auswertung ist etwa die Summierung der geleisteten Arbeitszeit eines Mitarbeiters in einem Zeitraum, wie sie für die Berichtsfunktion benötigt wird.

.Validierungsabfrage: geleistete Stunden je Mitarbeiter und Monat
[source,sql]
----
SELECT b.name,                                            -- <1>
       DATE_FORMAT(a.anwesenheits_datum, '%Y-%m') AS monat,
       SEC_TO_TIME(SUM(TIME_TO_SEC(a.stunden_differenz))) AS summe  -- <2>
FROM anwesenheitsaufzeichnungen a
JOIN benutzer b ON a.benutzer_id = b.benutzer_id          -- <3>
GROUP BY a.benutzer_id, monat                             -- <4>
ORDER BY b.name, monat;
----

<1> Der Join verknüpft jede Aufzeichnung mit dem zugehörigen Benutzernamen.
<2> Die einzelnen Zeitdifferenzen werden in Sekunden umgerechnet, summiert und wieder als Zeit formatiert.
<3> Die Verknüpfung erfolgt über die Fremdschlüsselbeziehung.
<4> Gruppiert wird je Mitarbeiter und Monat, sodass eine monatliche Übersicht entsteht.

Da diese und vergleichbare Abfragen korrekte und plausible Ergebnisse lieferten, gilt das Schema als validiert und für den produktiven Einsatz geeignet.

=== PHP als serverseitige Skriptsprache

Die Datenbank allein ist für den Endanwender nicht nutzbar; es bedarf einer Anwendungsschicht, die Daten entgegennimmt, verarbeitet und darstellt.
Diese Aufgabe übernimmt im Projekt die serverseitige Skriptsprache _PHP_.
Bevor die konkreten Datenbankzugriffe betrachtet werden, ist ein Verständnis des grundlegenden Ausführungsmodells von PHP notwendig.

==== Client-Server-Modell und Request-Response-Zyklus

Eine PHP-Webanwendung folgt dem _Client-Server-Modell_.
Der _Client_ – in der Regel ein Webbrowser – sendet eine Anfrage (Request) an den _Webserver_; dieser führt das PHP-Skript aus und sendet das erzeugte Ergebnis, meist eine HTML-Seite, als Antwort (Response) zurück.
Wichtig ist, dass PHP _vollständig auf dem Server_ ausgeführt wird: Der Client erhält niemals den PHP-Quelltext, sondern nur dessen Ausgabe.

[plantuml,format=svg]
----
@startuml
skinparam shadowing false
actor Benutzer
participant "Browser\n(Client)" as Browser
participant "Webserver\n+ PHP" as Server
database "MySQL/MariaDB" as DB

Benutzer -> Browser : Formular absenden
Browser -> Server : HTTP-Request (POST)
activate Server
Server -> DB : SQL-Abfrage
activate DB
DB --> Server : Ergebnismenge
deactivate DB
Server -> Server : HTML erzeugen
Server --> Browser : HTTP-Response (HTML)
deactivate Server
Browser -> Benutzer : Seite anzeigen
@enduml
----

Dieser Zyklus wiederholt sich bei jeder Interaktion.
Da jeder Request grundsätzlich unabhängig ist und PHP nach der Antwort seinen Zustand verliert, ist PHP von Natur aus _zustandslos_ – ein Umstand, der die weiter unten beschriebene Sitzungsverwaltung notwendig macht.

==== Verarbeitung von Formulardaten (GET und POST)

Die Kommunikation vom Client zum Server erfolgt überwiegend über HTML-Formulare.
Für die Übertragung der Formulardaten stehen zwei HTTP-Methoden zur Verfügung, die PHP in den superglobalen Arrays `$_GET` und `$_POST` bereitstellt.

* `GET` hängt die Parameter sichtbar an die URL an und eignet sich für unkritische, wiederholbare Abfragen wie das Nachladen von Daten.
* `POST` überträgt die Daten im Body des Requests und eignet sich für umfangreiche oder sensible Daten sowie für Vorgänge, die Daten verändern.

Im Projekt wird die Buchung der Arbeitszeit konsequent über `POST` abgewickelt, da sie den Datenbestand verändert.
Das folgende Beispiel aus der zentralen Datei `index.php` zeigt, wie eine Aktion aus dem Formular ausgelesen und verarbeitet wird.

.Auswerten einer Formularaktion in index.php
[source,php]
----
// Only process data on POST requests
if ($_SERVER['REQUEST_METHOD'] === 'POST') {                 // <1>
    // Determine which of the known buttons was pressed
    $action = key(array_intersect_key(
        $_POST,
        array_flip(['start','stop','start_pause','end_pause'])
    ));                                                       // <2>

    if ($action === 'start') {                               // <3>
        // Only start if no open session exists yet
        $existing = getActiveSession($link, $benutzer_id, $aktuelles_datum);
        if (!$existing) {
            $st = mysqli_prepare($link,
                "INSERT INTO anwesenheitsaufzeichnungen
                 (benutzer_id, anwesenheits_datum, start_arbeitszeit, ende_arbeitszeit)
                 VALUES (?, ?, CURTIME(), '00:00:00')");      // <4>
            mysqli_stmt_bind_param($st, "is", $benutzer_id, $aktuelles_datum);
            mysqli_stmt_execute($st);
            mysqli_stmt_close($st);
        }
    }
    // ... further actions (stop, breaks) follow analogously
}
----

<1> Es wird geprüft, ob es sich überhaupt um einen absendenden Request handelt.
<2> Aus den möglichen Buttons wird derjenige bestimmt, der im Formular tatsächlich übermittelt wurde.
<3> Verzweigung nach der gewählten Aktion.
<4> Beim Starten wird ein neuer Arbeitstag mit der aktuellen Serverzeit (`CURTIME()`) angelegt.

Bemerkenswert ist die fachliche Absicherung in Zeile <3>: Ein neuer Arbeitstag wird nur dann angelegt, wenn nicht bereits eine offene Sitzung existiert.
So wird verhindert, dass durch versehentliches doppeltes Klicken mehrere offene Buchungen für denselben Tag entstehen.

==== Sitzungsverwaltung mit Sessions

Da HTTP zustandslos ist, muss eine Anwendung auf andere Weise "wissen", welcher Benutzer gerade angemeldet ist.
Diese Aufgabe übernehmen _Sessions_ (Sitzungen).
Beim ersten Aufruf von `session_start()` erzeugt PHP eine eindeutige Session-ID, die als Cookie im Browser gespeichert wird; die zugehörigen Daten liegen auf dem Server im superglobalen Array `$_SESSION` und stehen so über mehrere Requests hinweg zur Verfügung.

Im Projekt wird nach erfolgreicher Anmeldung die Identität und Rolle des Benutzers in der Session abgelegt und auf jeder geschützten Seite geprüft.

.Schutz einer Seite über die Session
[source,php]
----
session_start();                                             // <1>
// Allow access only for logged-in users
if (!isset($_SESSION['loggedin']) || $_SESSION['loggedin'] !== true) {
    header("location: login.php");                           // <2>
    exit;                                                    // <3>
}
$benutzer_id = $_SESSION['id'];                              // <4>
$rolle       = $_SESSION['rolle'];
----

<1> Startet bzw. setzt die Sitzung fort und macht `$_SESSION` verfügbar.
<2> Nicht angemeldete Benutzer werden zur Login-Seite umgeleitet.
<3> `exit` verhindert, dass der restliche, geschützte Seiteninhalt überhaupt ausgeführt wird.
<4> Die in der Session hinterlegte Benutzer-ID steht für alle weiteren Abfragen bereit.

Über die ebenfalls gespeicherte Rolle lässt sich zusätzlich eine _Rechtekontrolle_ umsetzen.
So beginnen die administrativen Endpunkte mit einer Prüfung, ob die Rolle `Admin` oder `Manager` vorliegt, und brechen andernfalls mit dem HTTP-Statuscode 401 ab.

==== Sicherheitsaspekte (Authentifizierung, Passwort-Hashing)

Ein System, das personenbezogene Arbeitszeitdaten speichert, muss besonderen Wert auf Sicherheit legen.
Der zentrale Aspekt ist der Umgang mit Passwörtern.
Passwörter dürfen niemals im Klartext gespeichert werden, da sie bei einem Datenleck sofort missbraucht werden könnten.
Stattdessen wird ein _Hash_ gespeichert – ein nicht umkehrbarer Fingerabdruck des Passworts.

PHP stellt hierfür die Funktionen `password_hash()` und `password_verify()` bereit, die intern ein modernes, mit einem zufälligen _Salt_ versehenes Verfahren (standardmäßig bcrypt) verwenden (vgl. <<php-passwords>>).
Das folgende Beispiel aus der Registrierung zeigt das Erzeugen des Hashes.

.Sicheres Speichern eines Passworts bei der Registrierung
[source,php]
----
// Create a secure bcrypt hash including a random salt
$hashed_password = password_hash($password, PASSWORD_DEFAULT);     // <1>

$sql_insert = "INSERT INTO login_daten (benutzer_id, benutzername, passwort_hash)
               VALUES (?, ?, ?)";                                  // <2>
if ($stmt_insert = mysqli_prepare($link, $sql_insert)) {
    mysqli_stmt_bind_param($stmt_insert, "iss",
        $benutzer_id, $username, $hashed_password);                // <3>
    mysqli_stmt_execute($stmt_insert);
}
----

<1> `PASSWORD_DEFAULT` wählt automatisch das aktuell empfohlene Hash-Verfahren.
<2> Nur der Hash, nie das Klartext-Passwort, gelangt in die Datenbank.
<3> Die Werte werden als Parameter gebunden – dazu mehr im folgenden Kapitel.

Die Überprüfung bei der Anmeldung erfolgt spiegelbildlich mit `password_verify()`, das das eingegebene Passwort gegen den gespeicherten Hash prüft, ohne den Hash je entschlüsseln zu müssen.

.Überprüfung des Passworts beim Login
[source,php]
----
if (password_verify($password, $hashed_password)) {          // <1>
    $_SESSION["loggedin"] = true;                            // <2>
    $_SESSION["id"]       = $id;
    $_SESSION["rolle"]    = $rolle;
    header("location: index.php");
    exit;
} else {
    $login_err = "Ungültiger Benutzername oder Passwort.";    // <3>
}
----

<1> Vergleicht das eingegebene Passwort mit dem gespeicherten Hash.
<2> Nur bei Erfolg wird die Session als angemeldet markiert.
<3> Aus Sicherheitsgründen wird nicht verraten, ob Benutzername oder Passwort falsch war.

Ein weiteres bewusstes Sicherheitsdetail ist die identische, unspezifische Fehlermeldung in Zeile <3>.
Sie verhindert die sogenannte _User Enumeration_, bei der ein Angreifer aus unterschiedlichen Fehlermeldungen ableiten könnte, ob ein Benutzername existiert.

=== Datenbankzugriff mit PHP

Nachdem das Ausführungsmodell von PHP geklärt ist, widmet sich dieses Kapitel der eigentlichen Schnittstelle zwischen Anwendung und Datenbank.
Die Art und Weise dieses Zugriffs entscheidet maßgeblich über die Sicherheit der gesamten Anwendung.

==== Die MySQLi-Schnittstelle

Für den Zugriff auf MySQL-/MariaDB-Datenbanken bietet PHP zwei moderne Schnittstellen: _MySQLi_ und _PDO_.
Während PDO datenbankunabhängig ist, ist MySQLi (das "i" steht für _improved_) speziell auf MySQL zugeschnitten.
Im Projekt wurde die prozedurale Variante von MySQLi eingesetzt.
Der Verbindungsaufbau ist zentral in einer eigenen Konfigurationsdatei gekapselt.

.Zentraler Verbindungsaufbau in db_config.php
[source,php]
----
// Access data as constants
define('DB_SERVER', 'localhost');
define('DB_NAME', 'diplomprojekt');

// Establish the connection via the MySQLi extension
$link = mysqli_connect(DB_SERVER, DB_USERNAME, DB_PASSWORD, DB_NAME);  // <1>

if ($link === false) {                                                 // <2>
    die("FEHLER: Konnte keine Verbindung aufbauen. " . mysqli_connect_error());
}

mysqli_set_charset($link, "utf8mb4");                                  // <3>
----

<1> Baut die Verbindung auf und liefert ein Verbindungsobjekt zurück.
<2> Schlägt die Verbindung fehl, wird die Ausführung mit einer Meldung abgebrochen.
<3> Setzt den Zeichensatz auf `utf8mb4`, damit auch Umlaute und Sonderzeichen korrekt gespeichert werden.

Die Auslagerung in eine zentrale Datei folgt dem _DRY-Prinzip_ (Don't Repeat Yourself): Jede Seite, die Datenbankzugriff benötigt, bindet diese Datei mit `require_once` ein und verfügt damit über die Verbindung `$link`, ohne die Zugangsdaten zu wiederholen.

==== Prepared Statements und Parameterbindung

Die wichtigste Technik beim Datenbankzugriff sind _Prepared Statements_ (vorbereitete Anweisungen).
Dabei wird zunächst eine SQL-Anweisung mit _Platzhaltern_ (`?`) an die Datenbank gesendet und dort "vorbereitet"; erst danach werden die konkreten Werte separat übermittelt und an die Platzhalter _gebunden_.

Der entscheidende Punkt ist die strikte Trennung von _Anweisung_ und _Daten_.
Die Datenbank behandelt die gebundenen Werte ausschließlich als Daten und niemals als Teil des SQL-Befehls.
Das folgende Beispiel aus dem Login zeigt den vollständigen Ablauf.

.Prepared Statement bei der Anmeldung
[source,php]
----
$sql = "SELECT ld.benutzer_id, ld.passwort_hash, bp.rolle
        FROM login_daten ld
        JOIN benutzerprofile bp ON ld.benutzer_id = bp.benutzer_id
        WHERE ld.benutzername = ?";                          // <1>

if ($stmt = mysqli_prepare($link, $sql)) {                   // <2>
    mysqli_stmt_bind_param($stmt, "s", $username);           // <3>
    mysqli_stmt_execute($stmt);                              // <4>
    mysqli_stmt_store_result($stmt);

    if (mysqli_stmt_num_rows($stmt) == 1) {                  // <5>
        mysqli_stmt_bind_result($stmt, $id, $hashed_password, $rolle);
        mysqli_stmt_fetch($stmt);                            // <6>
        // ... password verification
    }
    mysqli_stmt_close($stmt);                                // <7>
}
----

<1> Die Abfrage enthält statt eines konkreten Werts den Platzhalter `?`.
<2> Die Anweisung wird vorbereitet.
<3> Der Benutzername wird als String (`"s"`) an den Platzhalter gebunden.
<4> Erst jetzt wird die Anweisung mit den gebundenen Daten ausgeführt.
<5> Es wird geprüft, ob genau ein passender Datensatz gefunden wurde.
<6> Die Ergebnisspalten werden an Variablen gebunden und ausgelesen.
<7> Das Statement wird geschlossen und gibt seine Ressourcen frei.

==== Schutz vor SQL-Injection

Die größte Gefahr beim Datenbankzugriff ist die _SQL-Injection_.
Dabei schleust ein Angreifer über ein Eingabefeld SQL-Code ein, der – bei unsicherer Programmierung – als Teil der Abfrage ausgeführt wird.
Würde der Benutzername etwa per einfacher String-Verkettung in die Abfrage eingesetzt, könnte eine Eingabe wie `' OR '1'='1` die Bedingung dauerhaft wahr machen und die Authentifizierung aushebeln.

[quote]
____
Prepared statements are very useful against SQL injections, because parameter values, which are transmitted later using a different protocol, need not be correctly escaped.
If the original statement template is not derived from external input, SQL injection cannot occur.
<<php-prepared>>
____

Genau hier liegt der Sicherheitsgewinn der im vorigen Abschnitt gezeigten Prepared Statements.
Da die gebundenen Werte niemals als SQL interpretiert werden, ist eine eingeschleuste Eingabe wie `' OR '1'='1` wirkungslos – sie wird lediglich als (nicht existierender) Benutzername gesucht.
Im gesamten Projekt werden daher alle Abfragen, die externe Eingaben verarbeiten, konsequent über Prepared Statements abgewickelt.

Wo Werte ausnahmsweise direkt in eine Abfrage eingesetzt werden, geschieht dies nur nach expliziter Typumwandlung in einen Integer, etwa mit `(int)$_GET['aid']`.
Auch diese Maßnahme verhindert eine Injection zuverlässig, weil das Ergebnis einer Integer-Umwandlung garantiert keinen SQL-Code mehr enthalten kann.

==== Fehlerbehandlung beim Datenbankzugriff

Robuste Anwendungen müssen damit rechnen, dass ein Datenbankzugriff fehlschlägt – sei es durch eine unterbrochene Verbindung oder eine fehlerhafte Abfrage.
Im Projekt wird die Fehlerbehandlung pragmatisch umgesetzt.

Bereits der Verbindungsaufbau wird, wie oben gezeigt, geprüft und bricht im Fehlerfall kontrolliert ab.
Bei den einzelnen Abfragen wird der Rückgabewert der Funktionen ausgewertet: `mysqli_prepare()` liefert im Fehlerfall `false`, sodass der nachfolgende Code nur bei erfolgreicher Vorbereitung ausgeführt wird.
Bei den AJAX-Endpunkten, die Daten an das clientseitige JavaScript liefern, wird im Fehlerfall ein definierter Wert wie ein leeres JSON-Array zurückgegeben, damit die Gegenseite stets eine verarbeitbare Antwort erhält.

Für einen produktiven Einsatz wäre eine zentralisierte Fehlerbehandlung mit Protokollierung (Logging) und benutzerfreundlichen, aber nicht zu detaillierten Fehlermeldungen empfehlenswert.
Detaillierte technische Fehlermeldungen sollten dabei nur protokolliert, dem Endbenutzer aber nicht angezeigt werden, da sie einem Angreifer Hinweise auf die interne Struktur geben könnten.

=== Integration von JavaScript in PHP

Die bisher beschriebenen Mechanismen erzeugen bei jeder Aktion eine komplett neue Seite.
Für eine moderne, reaktionsschnelle Bedienoberfläche ist es jedoch oft wünschenswert, einzelne Daten _nachzuladen_, ohne die ganze Seite neu aufzubauen.
Diese Aufgabe übernimmt clientseitiges JavaScript im Zusammenspiel mit den PHP-Endpunkten.

==== Zusammenspiel von Server- und Clientseite

Es ist wichtig, die Zuständigkeiten klar zu trennen.
PHP läuft auf dem _Server_ und hat Zugriff auf die Datenbank; JavaScript läuft im _Browser_ des Benutzers und steuert die Benutzeroberfläche.
Beide können nicht direkt aufeinander zugreifen, sondern kommunizieren über HTTP-Requests.

Eine typische Arbeitsteilung sieht so aus: JavaScript reagiert auf eine Benutzeraktion, fordert von einem PHP-Endpunkt Daten an, und PHP liefert diese Daten – nicht als fertige HTML-Seite, sondern in einem maschinenlesbaren Format zurück, das JavaScript anschließend in die Oberfläche einfügt.

==== Ausgabe dynamischer JavaScript-Inhalte aus PHP

Eine einfache Form der Integration besteht darin, dass PHP beim Erzeugen der Seite Daten direkt in den JavaScript-Code "hineinschreibt".
Da PHP letztlich nur Text ausgibt, kann es serverseitig bekannte Werte unmittelbar in ein `<script>`-Element einsetzen.
Besonders sauber gelingt dies mit der Funktion `json_encode()`, die einen PHP-Wert in gültige JavaScript-/JSON-Syntax übersetzt.

.Übergabe von PHP-Daten an JavaScript per json_encode()
[source,php]
----
<button onclick='openEditModal(<?php echo json_encode($e); ?>)'>
    Bearbeiten
</button>
----

In diesem Beispiel wird der PHP-Datensatz `$e` in ein JavaScript-Objekt umgewandelt und direkt als Argument des Klick-Handlers eingesetzt.
Auf diese Weise stehen die serverseitigen Daten der Funktion `openEditModal()` unmittelbar als JavaScript-Objekt zur Verfügung, ohne dass ein zusätzlicher Request nötig wäre.

==== Asynchrone Datenübertragung mit AJAX

Sollen Daten hingegen _nach_ dem Laden der Seite und ohne Neuladen abgerufen werden, kommt _AJAX_ (Asynchronous JavaScript and XML) zum Einsatz.
Trotz des historischen Namens werden heute überwiegend keine XML-, sondern JSON-Daten ausgetauscht.
Moderne Browser stellen dafür die `fetch()`-Funktion bereit, die einen HTTP-Request im Hintergrund absetzt und das Ergebnis asynchron verarbeitet.

Der grundlegende Ablauf einer solchen asynchronen Anfrage lässt sich als Sequenz darstellen.

[plantuml,format=svg]
----
@startuml
skinparam shadowing false
participant "Browser\n(JavaScript)" as JS
participant "PHP-Endpunkt\n(get_pausen.php)" as PHP
database "Datenbank" as DB

JS -> PHP : fetch('get_pausen.php?aid=123')
activate PHP
PHP -> DB : SELECT ... WHERE anwesenheit_id = 123
activate DB
DB --> PHP : Ergebnismenge
deactivate DB
PHP --> JS : JSON-Array
deactivate PHP
JS -> JS : DOM aktualisieren\n(Pausenzeilen einfügen)
@enduml
----

Der Vorteil liegt auf der Hand: Während des Nachladens bleibt die Seite bedienbar, und nur der tatsächlich benötigte Datenausschnitt wird übertragen.

==== Datenaustausch im JSON-Format

Das Bindeglied zwischen PHP und JavaScript ist das _JSON_-Format (JavaScript Object Notation).
Es ist ein leichtgewichtiges, textbasiertes Format, das sowohl für Menschen lesbar als auch von Maschinen einfach zu verarbeiten ist.
PHP erzeugt JSON mit `json_encode()`, JavaScript wandelt es mit der `json()`-Methode der Antwort wieder in ein Objekt um.

Der serverseitige Endpunkt `get_pausen.php` zeigt, wie kompakt ein solcher JSON-Dienst sein kann.

.JSON-Endpunkt get_pausen.php (serverseitig)
[source,php]
----
header('Content-Type: application/json');                    // <1>
$aid = (int)($_GET['aid'] ?? 0);                             // <2>
if (!$aid) { echo '[]'; exit; }                              // <3>
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

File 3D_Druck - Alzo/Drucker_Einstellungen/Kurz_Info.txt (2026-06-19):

Drucker & Status

Drucker: Bambu Lab P2S
Düse: 0,4 mm, Fluss Standard
Hotend-Temp: 255/255 °C
Druckbett-Temp: 70/70 °C
Kammertemperatur: 41 °C
Lüfter: 100%
Luftfeuchtigkeit Filament: 17%

Filament-Setup (AMS, 4 Slots)

A1: Leer
A2: PETG
A3: ASA
A4: PETG (aktiv – pink markiert, dieser Slot wird gedruckt)
Externer Spool: nicht definiert ("?")
Im Slicer eingestellt: Generic PETG

Druckauftrag
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

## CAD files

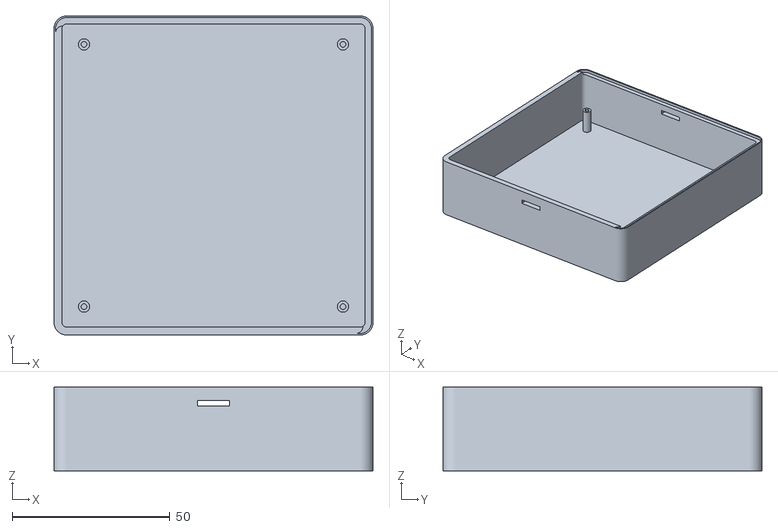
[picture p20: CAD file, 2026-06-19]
3D_Druck - Alzo/1_Design_3D-Druck/TimeCortex_Unten.stl
101.0 x 101.0 x 26.5

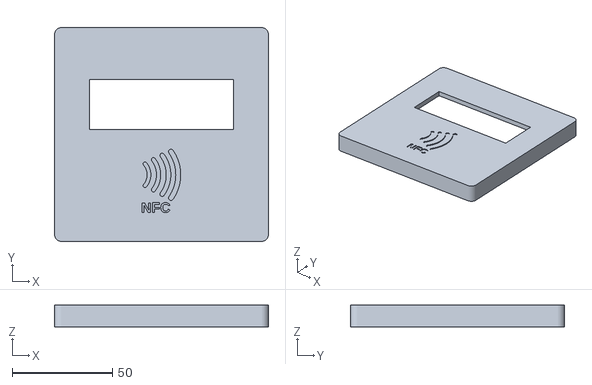
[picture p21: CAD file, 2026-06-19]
3D_Druck - Alzo/2_Design_3D-Druck/case-Deckel.stl
106.6 x 106.6 x 10.9

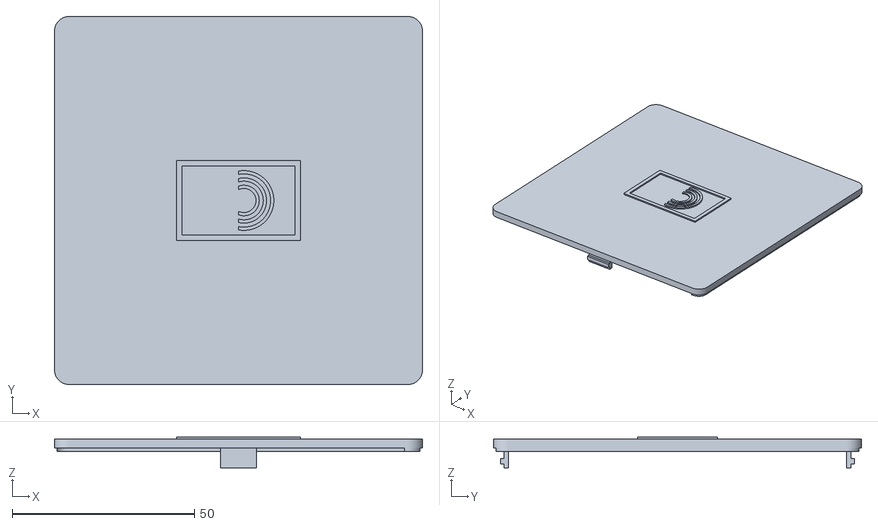
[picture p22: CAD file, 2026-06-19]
3D_Druck - Alzo/1_Design_3D-Druck/TimeCortex_Deckel.stl
101.0 x 101.0 x 8.50

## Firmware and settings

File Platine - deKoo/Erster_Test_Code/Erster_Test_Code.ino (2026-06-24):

#include <Wire.h>
#include <Adafruit_PN532.h>

#define SDA_PIN 5
#define SCL_PIN 4

Adafruit_PN532 nfc(-1, -1); // I2C

void setup() {
  Serial.begin(115200);
  delay(1500);

  Serial.println("START");
  Wire.begin(SDA_PIN, SCL_PIN);
  Wire.setClock(100000);

  Serial.println("PN532 begin...");
  nfc.begin();

  Serial.println("Read firmware...");
  uint32_t v = nfc.getFirmwareVersion();
  if (!v) {
    Serial.println("FAIL: PN532 nicht gefunden (I2C NACK / falscher Modus / Verkabelung).");
    while (1) delay(1000);
  }

  Serial.print("OK: PN532 FW = 0x");
  Serial.println(v, HEX);

  nfc.SAMConfig();
  Serial.println("SAMConfig OK. Halte eine Karte dran...");
}

void loop() {
  uint8_t uid[7];
  uint8_t uidLength;

  bool ok = nfc.readPassiveTargetID(PN532_MIFARE_ISO14443A, uid, &uidLength);

  if (ok) {
    Serial.print("UID: ");
    for (uint8_t i = 0; i < uidLength; i++) {
      if (uid[i] < 0x10) Serial.print("0");
      Serial.print(uid[i], HEX);
      if (i < uidLength - 1) Serial.print(" ");
    }
    Serial.println();
    delay(800);
  }
}
